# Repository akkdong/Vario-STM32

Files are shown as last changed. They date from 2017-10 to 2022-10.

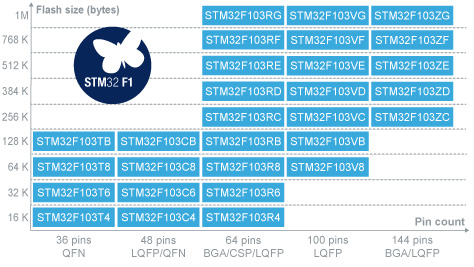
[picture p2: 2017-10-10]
doc/en.STM32F103_line_LN1565.jpg

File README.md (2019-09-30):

# Variometer with STM32

## Variometer Features
* Calculate Vertical Velocity : uses sensor fusion(pressure & accelleration)
* Vario sound
* Receive GPS data
* IGC Logging : save to SD-Card
* BT connectivity : support GPS & Vario NMEA setences
* Firmware update : support Windows application that updates using USB2Serial
* Function Key
	* Change sound level (mute, low, loud)
	* UMS On/Off
	* Calibration On/Off
* Accllerator calibration
* Configuration console
	* View & Update parameters
	* Interactive calibration
	* Support Window or Android applicatioin that uses USB2Serial or BT
* One key Power on/off
* Self Power off
* Low battery detection
* USB suppport : UMS(USB mass stroage), USB2Serial
	* UMS can be enabled by Function key or when power on while functin key is pressed.
	* USB2Serial supports Firmware update & Debugging\
* Status LED : Power, MCU, GPS, BT status notify

## Hardware specifications
* STM32F103CB Processor
* 10DOF IMU : MPU6050, HMC5883, MS5611
* 66ch GPS module : AKS6C
* BT : Bluetooth Specifcation 2.1 support, Calss2, SPP
* Li-po battery & Charger
* Push button On/Off controller
* SD card
* USB : UMS, USB to Serial, DFU
* EEPROM : 32KB I2C
* Piezo speaker

## Device modes
* Vario : default mode
* UMS
* Calibration
* Configuration

## Vario modes
* Init
* Landing
* Flying
* Halt

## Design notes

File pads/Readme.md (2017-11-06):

# Known bugs

* Power on/off does not work.
  * LTC2950 EN pin needs external pull-up.
  * MAX1676 does not cut-off output voltage on shutdown mode
* Charging LED does not turn off even when fullly charged

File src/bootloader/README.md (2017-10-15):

# STM32duino-bootloader

Modify Node. I modify original STM32duino-bootloader for my variometer boards.

Please Note. This code does not work with all STM32F103 Boards

Also Note. Use GCC 4.8 (not 4.9 or newer, as these versions have more aggressive optimisation which causes hardware registers not be read correctly and consequently the bootloader does not work)

Bootloader for STM32F103 boards, for use with the Arduino_STM32 repo and the Arduino IDE

This repo is a derivation of  https://github.com/jonatanolofsson/maple-bootloader (mini-boot branch) which is in turn a derivation of the maple-bootloader created by Leaflabs http://github.com/leaflabs/maple-bootloader

The bootloader has been reworked so that all versions are contained in the Master branch, rather than 1 branch per version / board.

Note.
The upload to RAM option has effectively been removed, as it was useless and caused problems.
The bootloader still has a DFU - AltID for RAM uploads, however this returns an error the host attempts to uplaod to this AltID. The AltID was kept, to allow backwards compatibility with anyone still using the old Maple IDE which has a upload to RAM option.

The makefile now has multple build targets including "maple-mini" (roughly equivalent to the old mini-boot branch), maple-rev3 etc etc.

Additionally the bootloader now works with "generic" STM32F103 boards, which do not have the additional USB reset hardware which all Maple, and Maple mini boards have.

On "generic" boards, the USB reset (to force re-enumeration by the host), is triggered by reconfiguring USB line D+ (PA12) into GPIO mode, and driving PA12 low for a short period, before setting the pin back to its USB operational mode.
This system to reset the USB was written by @Victor_pv.
Note. It is not guaranteed to work on all "generic" STM32 boards, and relies on PA12 having a pull-up resistor of around 1.5k - however most "generic" boards seem to have this.
Its unclear if this method to reset the USB bus conforms precisely to the USB standard, but it seems to work fine on all PC's and Mac's (and Linux boxes) on which its been tested - and seems usable for hobby / non commericial / non-critical systems.

There are multiple build targets for "generic" STM32F103 boards, because each vendor seems to have the "LED" on a different port/pin, and the bootloader flashes the LED to indicate the current operation / state.

So if your board has an LED on pin PC13 the makefile target is "generic-pc13" . At the time of writing the following geneirc targets are available (more may be added without this readme being updated each time, so please check the makefile to see the latest list of build targets)

generic-pc13
generic-pg15
generic-pd2
generic-pd1
generic-pa1
generic-pb9

In addition to the LED, the difference in the build targets is
(a) whether the device has maple USB reset hardware.
(b) Which pin the "button" is attached to.

Note. Most "generic" STM32F103 boards only have a reset button, and not a user / test button. So the bootloader code always configures the Button input pin as PullDown,  hence if a button is not present on the Button pin (Default is PC14), the pin should remain in a LOW state, and the bootloader will assume that the Button is not being pressed.

IMPORTANT.
If you have a board where you have external hardware attached to pin PC12 which will pull this pin HIGH, you will need to make a new build target for you board which uses a different pin for the Button, or completely modify the code so that the Button is ignored.

The configuration for each build target / board is defined in config.h

The Makefile sets the board name as a #define e.g. #define TARGET_GENERIC_F103_PD2, and config.h contains a block of config defines for each board.

e.g.

```
#define HAS_MAPLE_HARDWARE 1
#define LED_BANK GPIOB
#define LED_PIN 1
#define LED_ON_STATE 1
/* On the Mini, BUT is PB8 */
#define BUTTON_BANK GPIOB
#define BUTTON 8
/* USB Disc Pin Setup. USB DISC is PB9 */
#define USB_DISC_BANK GPIOB
#define USB_DISC 9
#define USER_CODE_RAM ((u32)0x20000C00)
#define RAM_END ((u32)0x20005000)
```

Boards which have the Maple USB reset hardware need to defined HAS_MAPLE_HARDWARE

There are definitions for LED_BANK (GPIO Port)
LED pin (Pin in that port)
LED_ON_STATE ( Whether the LED is lit when the pin is high (1) or low (0) - Note. this is because some generic boards have the LED between Vcc and the pin, hence are on when the LED PIN is LOW)

Button bank (port) and pin

For boards with Maple hardware, the "Disconnect" pin USB_DISC need to be defined.
On generic" boards, as this is always PA12 - as USB D+ is always on this pin on STM32F103 devices.
(Note. For generic boards, this define could probably be moved to the usb code as it never changes)

Note.
USER_CODE_RAM and RAM_END are allways the same, and probably need to be consolodated, rather than being defined for each board.

There is no longer a need to configure FLASH SIZE, as this is now detemined by reading the size from a register in the processor.
The Flash page (and hence DFU upload block size) no longer needs to be defined either, as the flash page size is inferred from the total flash size. All devices up to 128kb have a 1k page size, and any board with more then 128k flash have a 2k page size.

Note the code directly links flash page size to DFU block size. It would probably be possible to decouple this and possibly increase upload speeds, but it has not been done as yet.

#####Other improvements on the original Maple bootloader

1. Smaller footprint - now only 8k (This became possible due to code changes by @jonatanolofsson which allowed the GCC optimisation for size flag to be used
2. Additional DFU AltID upload type was added, which allows the sketch to be loaded at 0x8002000 instead of 0x8005000 (due to reduce size of the bootloader is self),
Note. upload to 0x8005000 was retained for backwards compatibility.

If you have questions about the bootloader please raise and issue and I will attempt to answer them.

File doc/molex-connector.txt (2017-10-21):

53047 1.25 pitch Vertical
53048 1.25 pitch Right Angle

51021 1.25 pitch Wire-to-Wire & Wire-to-Board Housing, Female

53398 1.25 pitch Surface Mount, Vertical
53262 1.25 pitch Surface Mount, Right Angle

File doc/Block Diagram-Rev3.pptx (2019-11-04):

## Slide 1

USB

Charger

Regulator

MCU

VCC_USB

VCC_BAT

Reset

VCC_MCU

Battery

VCC_BAT+

Regulator

VCC_PERI1

GPS

BT

Regulator

VCC_PERI2

EEPROM

MMC

EPD

Load Switch

VCC_EXT

IMU

PIEZO

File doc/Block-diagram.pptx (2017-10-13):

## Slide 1

STM32F103C

USB

D+

D-

DISC

I2C1_SCL

I2C1_SDA

IMU

Regulator

VCC

PWM_H

PWM_L

Buzzer

Charger

LiPo

S/W

Regulator

ACC

UART1_RX

UART1_TX

GPS

UART2_RX

UART2_TX

BT

Voltage
Divider

JTAG

SD-Card

SPI2_SCLK

SD_CS

SPI2_MOSI

ADC_POWER

EEPROM

SPI2_MISO

EE_CS

JNTRST

JTDI

JTMS

JTCK

BTN_RESET

JTDO

LED_POWER

NRST

Button

Button

Button

BTN_BOOT

BTN_EXTRA

LED_STATE1

LED_STATE2

LED

LED

LED

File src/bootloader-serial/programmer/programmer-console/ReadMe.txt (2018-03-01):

========================================================================
    콘솔 응용 프로그램 : programmer-console 프로젝트 개요
========================================================================

응용 프로그램 마법사에서 이 programmer-console 응용 프로그램을 만들었습니다.

programmer-console 응용 프로그램을 구성하는 각 파일에 대한
요약 설명이 포함되어 있습니다.

programmer-console.vcxproj
    응용 프로그램 마법사를 사용하여 생성한 VC++ 프로젝트의 기본 프로젝트 파일입니다. 파일을 생성한 Visual C++ 버전에 대한 정보와 응용 프로그램 마법사를 사용하여 선택한 플랫폼, 구성 및 프로젝트 기능에 대한 정보가 포함되어 있습니다.

programmer-console.vcxproj.filters
    응용 프로그램 마법사를 사용하여 생성된 VC++ 프로젝트의 필터 파일입니다. 이 파일에는 프로젝트의 파일과 필터 간의 연결 정보가 들어 있습니다. 이러한 연결은 특정 노드에서 유사한 확장명으로 그룹화된 파일을 표시하기 위해 IDE에서 사용됩니다. 예를 들어 ".cpp" 파일은 "소스 파일" 필터와 연결되어 있습니다.

programmer-console.cpp
    기본 응용 프로그램 소스 파일입니다.

/////////////////////////////////////////////////////////////////////////////
기타 표준 파일:

StdAfx.h, StdAfx.cpp
    이 파일은 미리 컴파일된 헤더(PCH) 파일 programmer-console.pch와 미리 컴파일된 형식(PCT) 파일 StdAfx.obj를 빌드하는 데 사용됩니다.

/////////////////////////////////////////////////////////////////////////////
기타 참고:

응용 프로그램 마법사에서 사용하는 "TODO:" 주석은 사용자가 추가하거나 사용자 지정해야 하는 소스 코드 부분을 나타냅니다.

/////////////////////////////////////////////////////////////////////////////

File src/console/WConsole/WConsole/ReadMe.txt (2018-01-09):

================================================================================
    MFC 라이브러리 : wconsole 프로젝트 개요
===============================================================================

응용 프로그램 마법사에서 이 wconsole 응용 프로그램을 만들었습니다. 이 응용 프로그램은 MFC의 기본 사용법을 보여 줄 뿐만 아니라 응용 프로그램을 작성하기 위한 기본 구조를 제공합니다.

wconsole 응용 프로그램을 구성하는 각 파일에 대한
요약 설명이 포함되어 있습니다.

wconsole.vcxproj
    응용 프로그램 마법사를 사용하여 생성한 VC++ 프로젝트의 기본 프로젝트 파일입니다. 파일을 생성한 Visual C++ 버전에 대한 정보와 응용 프로그램 마법사를 사용하여 선택한 플랫폼, 구성 및 프로젝트 기능에 대한 정보가 포함되어 있습니다.

wconsole.vcxproj.filters
    응용 프로그램 마법사를 사용하여 생성된 VC++ 프로젝트의 필터 파일입니다. 이 파일에는 프로젝트의 파일과 필터 간의 연결 정보가 들어 있습니다. 이러한 연결은 특정 노드에서 유사한 확장명으로 그룹화된 파일을 표시하기 위해 IDE에서 사용됩니다. 예를 들어 ".cpp" 파일은 "소스 파일" 필터와 연결되어 있습니다.

wconsole.h
    해당 응용 프로그램의 기본 헤더 파일입니다.
    여기에는 resource.h를 비롯한 다른 프로젝트별 헤더가 포함되어 있으며 CVarioConsoleApp 응용 프로그램 클래스가 선언되어 있습니다.

wconsole.cpp
    이는 응용 프로그램 클래스 CVarioConsoleApp가 포함된 기본 응용 프로그램 소스 파일입니다.

wconsole.rc
    프로그램에서 사용하는 모든 Microsoft Windows 리소스의 목록입니다. 여기에는 RES 하위 디렉터리에 저장된 아이콘, 비트맵 및 커서가 포함됩니다. 이 파일은 Microsoft Visual C++에서 직접 편집할 수 있습니다. 프로젝트 리소스는 1042에 있습니다.

res\wconsole.ico
    아이콘 파일이며, 응용 프로그램의 아이콘으로 사용됩니다. 이 아이콘은 기본 리소스 파일인 wconsole.rc에 의해 포함됩니다.

res\wconsole.rc2
    이 파일에는 Microsoft Visual C++ 이외의 다른 도구에서 편집한 리소스가 포함되어 있습니다. 리소스 편집기로 편집할 수 없는 모든 리소스는 이 파일에 넣어야 합니다.

/////////////////////////////////////////////////////////////////////////////

응용 프로그램 마법사에서 대화 상자 클래스 하나를 만듭니다.

VarioConsoleDlg.h, VarioConsoleDlg.cpp - 대화 상자
    이 파일에는 CVarioConsoleDlg 클래스가 포함됩니다. 이 클래스는 응용 프로그램의 주 대화 상자에 대한 동작을 정의합니다. 이 대화 상자 템플릿은 wconsole.rc에 있으며, Microsoft Visual C++에서 직접 편집할 수 있습니다.

/////////////////////////////////////////////////////////////////////////////

기타 기능:

ActiveX 컨트롤
    응용 프로그램이 Active X 컨트롤을 지원합니다.

/////////////////////////////////////////////////////////////////////////////

기타 표준 파일:

StdAfx.h, StdAfx.cpp
    이 파일은 미리 컴파일된 헤더(PCH) 파일 wconsole.pch와 미리 컴파일된 형식(PCT) 파일 StdAfx.obj를 빌드하는 데 사용됩니다.

Resource.h
    새 리소스 ID를 정의하는 표준 헤더 파일입니다. Microsoft Visual C++에서 이 파일을 읽고 업데이트합니다.

wconsole.manifest
	응용 프로그램 매니페스트 파일은 Windows XP에서 특정 버전의 Side-by-Side 어셈블리에 대한 응용 프로그램 종속성을 설명하는 데 사용됩니다. 로더는 이 정보를 통해 어셈블리 캐시 또는 응용 프로그램의 private에서 적절한 어셈블리를 로드합니다. 응용 프로그램 매니페스트는 응용 프로그램 실행 파일과 같은 폴더에 설치된 외부 .manifest 파일 형태로서 재배포용으로 포함되거나, 리소스 형태로 된 실행 파일에 포함될 수 있습니다.
/////////////////////////////////////////////////////////////////////////////

기타 참고:

응용 프로그램 마법사에서 사용하는 "TODO:"는 사용자가 추가하거나 사용자 지정해야 하는 소스 코드 부분을 나타냅니다.

공유된 DLL에서 MFC를 사용하는 응용 프로그램의 경우 MFC DLL을 재배포할 필요가 없습니다. 응용 프로그램에서 운영 체제의 로캘과 다른 언어를 사용하는 경우 이에 해당하는 지역화된 리소스인 mfc110XXX.DLL도 재배포해야 합니다.
이러한 두 항목에 대한 자세한 내용은 MSDN 설명서에 있는 Visual C++ 응용 프로그램 재배포 섹션을 참조하십시오.

/////////////////////////////////////////////////////////////////////////////

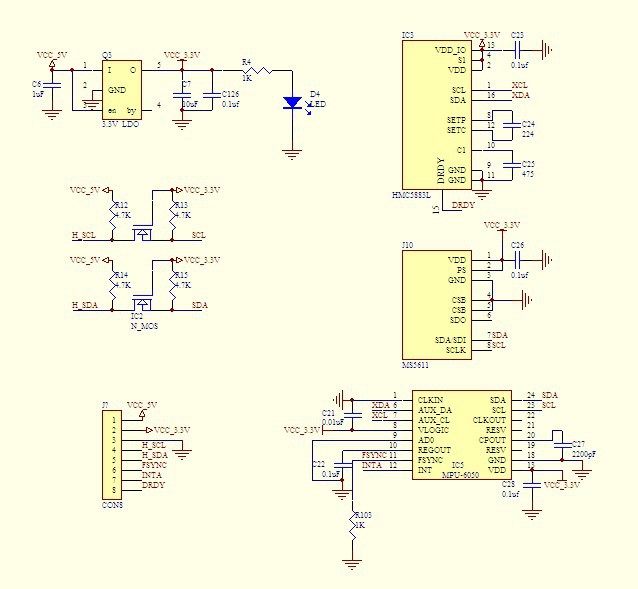
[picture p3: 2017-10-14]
doc/GY-86_Schematic.jpg

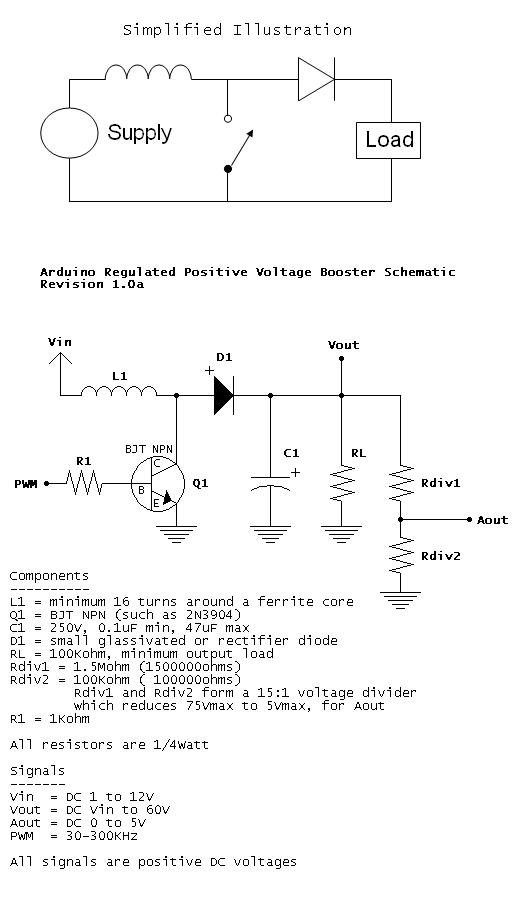
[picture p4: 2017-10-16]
doc/piezo/RegVoltageBoosterSchematic.jpg

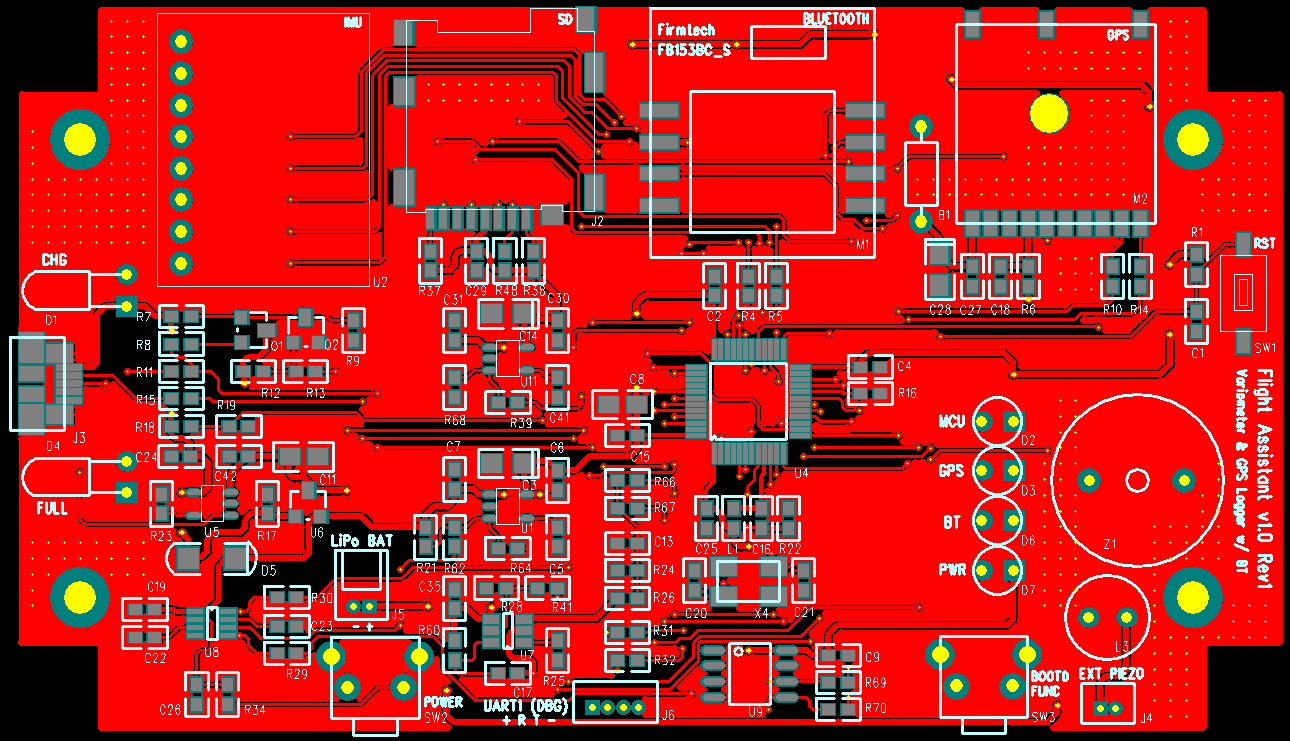
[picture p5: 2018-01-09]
doc/pcb/pcb-top-rev2.png

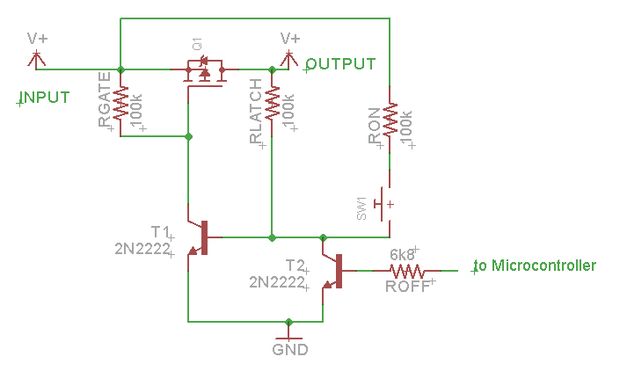
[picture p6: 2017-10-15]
doc/auto power off - 1.jpg

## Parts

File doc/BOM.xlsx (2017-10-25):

Item | Qty | Reference | Part Name | Note
1 | 1 | Q3 | 2SC2383
2 | 3 | U1 U6 U10 | AO3401A
3 | 1 | U9 | AT24C256C | 32KB, I2C
4 | 2 | Q1-2 | BC817-16LT1 | generic NPN transistor
5 | 2 | B1 L1 | BEAD-0603(1608) | 47nH, 300mA
6 | 1 | Z1 | BUZZER | BPE-1404P or BPE-1407P
7 | 1 | C13 | C-N-0603(1608),0.01uF
8 | 16 | C1-2 C4 C6-7 C9 C12 C15-16 C18-19 C22 C24-27 | C-N-0603(1608),0.1uF
9 | 1 | C23 | C-N-0603(1608),0.47uF
10 | 1 | C17 | C-N-0603(1608),1uF
11 | 2 | C20-21 | C-N-0603(1608),20pF
12 | 1 | C5 | C-N-0603(1608),470pF
13 | 1 | C8 | C-N-0805(2012),10uF
14 | 3 | C3 C11 C28 | C-P-0805(2012),10uF
15 | 2 | C10 C14 | C-P-0805(2012),47uF
16 | 1 | L2 | COIL,22uH | SC4532
17 | 1 | L3 | COIL,48mH | RLB0812-22mH/33mH/47mH
18 | 2 | D5 D8 | D-1206(3216),S1M | 1N4004
19 | 1 | M1 | FB153BC_S
20 | 1 | M2 | FGPMMOPA6C
21 | 1 | U2 | GY-86
22 | 6 | D1-4 D6-7 | LED | R/G/Y/B, R/G
23 | 1 | U8 | LTC2950-1
24 | 1 | U7 | MAX1676
25 | 1 | U5 | MCP73831
26 | 4 | X1-3 X5 | MHOLE | 3mm hole, 4mm pad
27 | 1 | U3 | MIC5219-3.3BM5
28 | 1 | J1 | MOLEX-54048-08 | & 51021-08 housing
29 | 1 | J2 | MOLEX-TFLASH-49225-0821
30 | 14 | R4-6 R10 R14 R22 R31-32 R44 R46-47 R49-51 | R-0603(1608),0R
31 | 1 | R8 | R-0603(1608),1.5K
32 | 3 | R3 R21 R45 | R-0603(1608),100K
33 | 17 | R1 R7 R16-17 R27 R35 R37-43 R48 R53-54 R58 R60-61 | R-0603(1608),10K
34 | 1 | R18 | R-0603(1608),15K
35 | 6 | R13 R52 R55-57 R59 | R-0603(1608),1K
36 | 1 | R24 | R-0603(1608),1M
37 | 1 | R28 | R-0603(1608),200R
38 | 1 | R19 | R-0603(1608),22K
39 | 2 | R11 R15 | R-0603(1608),22R | replace 47R
40 | 1 | R30 | R-0603(1608),240K
41 | 1 | R26 | R-0603(1608),270K
42 | 1 | R23 | R-0603(1608),2K
43 | 1 | R29 | R-0603(1608),330K
44 | 1 | R9 | R-0603(1608),33K
45 | 2 | R33 R36 | R-0603(1608),4.7K
46 | 2 | R2 R20 | R-0603(1608),470R
47 | 1 | R12 | R-0603(1608),47K
48 | 1 | R34 | R-0603(1608),5K | replace 4.7K
49 | 1 | R25 | R-0603(1608),NC
50 | 2 | J4-5 | SIP_02 | 54048, 54047 & 51021 housing
51 | 1 | J6 | SIP_04 | & 51021 housing
52 | 1 | U4 | STM32F103C
53 | 3 | SW1-3 | SW-SPST-ITS-1164 | 1/2-KLT-1105VE, 3-SMD Tact
54 | 1 | J3 | USB_TYPEB_MINI | MOLEX-47346-0001
55 | 1 | X4 | XTAL-SMD,8MHz | 3x5 size

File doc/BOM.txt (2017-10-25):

Item	Qty	Reference	Part Name
1	1	Q3	2SC2383
2	3	U1 U6 U10	AO3401A
3	1	U9	AT24C256C
4	2	Q1-2	BC817-16LT1
5	2	B1 L1	BEAD-0603(1608)
6	1	Z1	BUZZER
7	1	C13	"C-N-0603(1608),0.01uF"
8	16	C1-2 C4 C6-7 C9 C12 C15-16 C18-19 C22 C24-27	"C-N-0603(1608),0.1uF"
9	1	C23	"C-N-0603(1608),0.47uF"
10	1	C17	"C-N-0603(1608),1uF"
11	2	C20-21	"C-N-0603(1608),20pF"
12	1	C5	"C-N-0603(1608),470pF"
13	1	C8	"C-N-0805(2012),10uF"
14	3	C3 C11 C28	"C-P-0805(2012),10uF"
15	2	C10 C14	"C-P-0805(2012),47uF"
16	1	L2	"COIL,22uH"
17	1	L3	"COIL,48mH"
18	2	D5 D8	"D-1206(3216),S1M"
19	1	M1	FB153BC_S
20	1	M2	FGPMMOPA6C
21	1	U2	GY-86
22	6	D1-4 D6-7	LED
23	1	U8	LTC2950-1
24	1	U7	MAX1676
25	1	U5	MCP73831
26	4	X1-3 X5	MHOLE
27	1	U3	MIC5219-3.3BM5
28	1	J1	MOLEX-54048-08
29	1	J2	MOLEX-TFLASH-49225-0821
30	14	R4-6 R10 R14 R22 R31-32 R44 R46-47 R49-51	"R-0603(1608),0R"
31	1	R8	"R-0603(1608),1.5K"
32	3	R3 R21 R45	"R-0603(1608),100K"
33	17	R1 R7 R16-17 R27 R35 R37-43 R48 R53-54 R58 R60-61	"R-0603(1608),10K"
34	1	R18	"R-0603(1608),15K"
35	6	R13 R52 R55-57 R59	"R-0603(1608),1K"
36	1	R24	"R-0603(1608),1M"
37	1	R28	"R-0603(1608),200R"
38	1	R19	"R-0603(1608),22K"
39	2	R11 R15	"R-0603(1608),22R"
40	1	R30	"R-0603(1608),240K"
41	1	R26	"R-0603(1608),270K"
42	1	R23	"R-0603(1608),2K"
43	1	R29	"R-0603(1608),330K"
44	1	R9	"R-0603(1608),33K"
45	2	R33 R36	"R-0603(1608),4.7K"
46	2	R2 R20	"R-0603(1608),470R"
47	1	R12	"R-0603(1608),47K"
48	1	R34	"R-0603(1608),5K"
49	1	R25	"R-0603(1608),NC"
50	2	J4-5	SIP_02
51	1	J6	SIP_04
52	1	U4	STM32F103C
53	3	SW1-3	SW-SPST-ITS-1164
54	1	J3	USB_TYPEB_MINI
55	1	X4	"XTAL-SMD,8MHz"

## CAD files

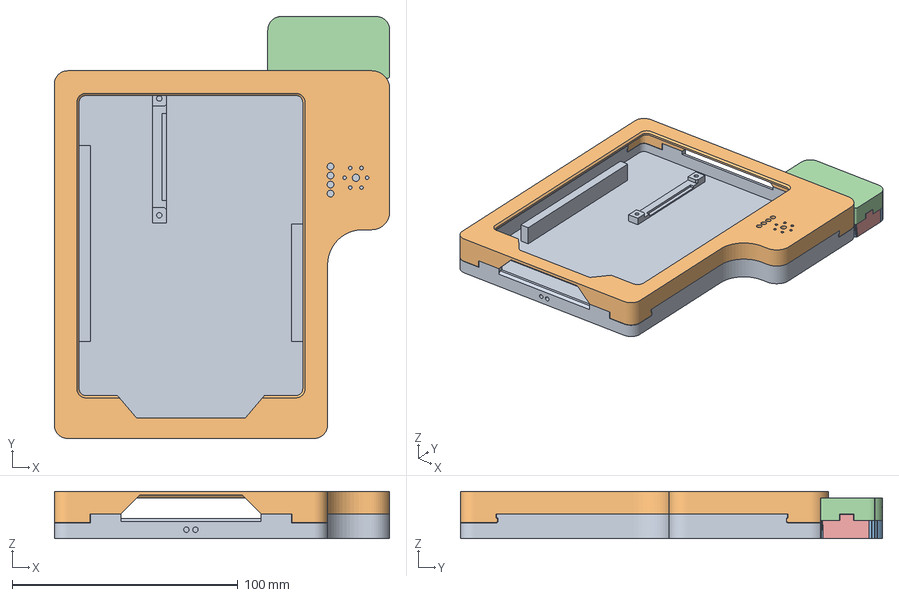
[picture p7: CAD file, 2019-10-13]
case/Kobo.FCStd
148.5 x 186.8 x 21.0 mm
Bottom
Cover
Antenna-Horz-Bottom
Antenna-Horz-Cover
Antenna-Horz-Bottom (Meshed)
Antenna-Horz-Cover (Meshed)

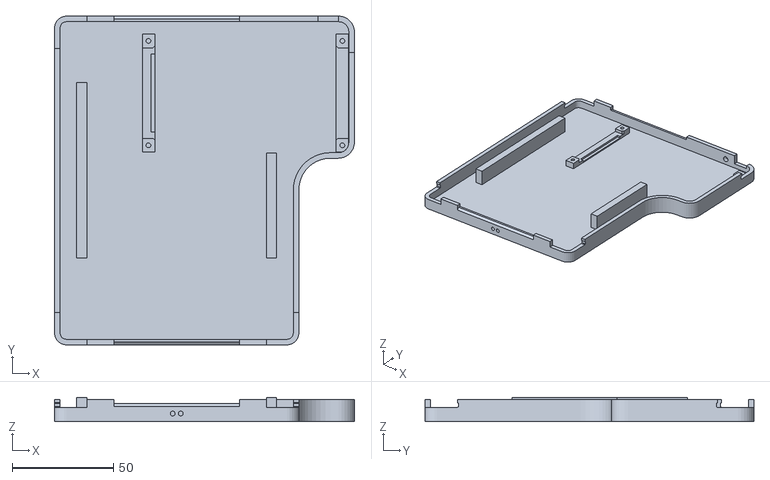
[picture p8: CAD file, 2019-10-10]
case/Kobo-Bottom.stl
148.5 x 162.8 x 12.0

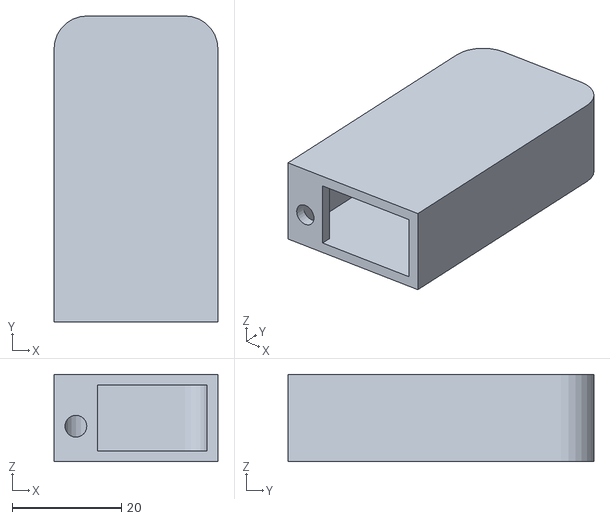
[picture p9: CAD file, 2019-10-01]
case/Kobo-Antenna.stl
30.0 x 56.0 x 16.0

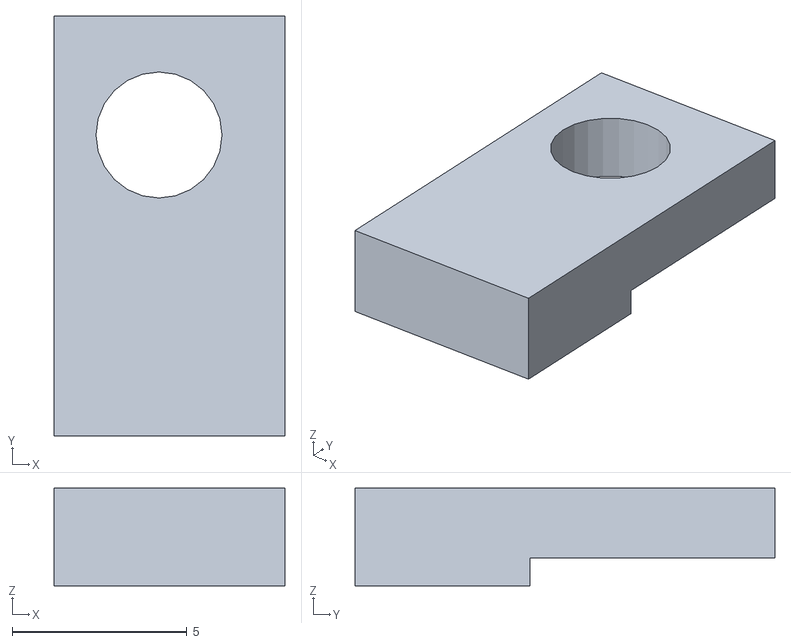
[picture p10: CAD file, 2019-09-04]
case/VarioFix.stl
6.60 x 12.0 x 2.80

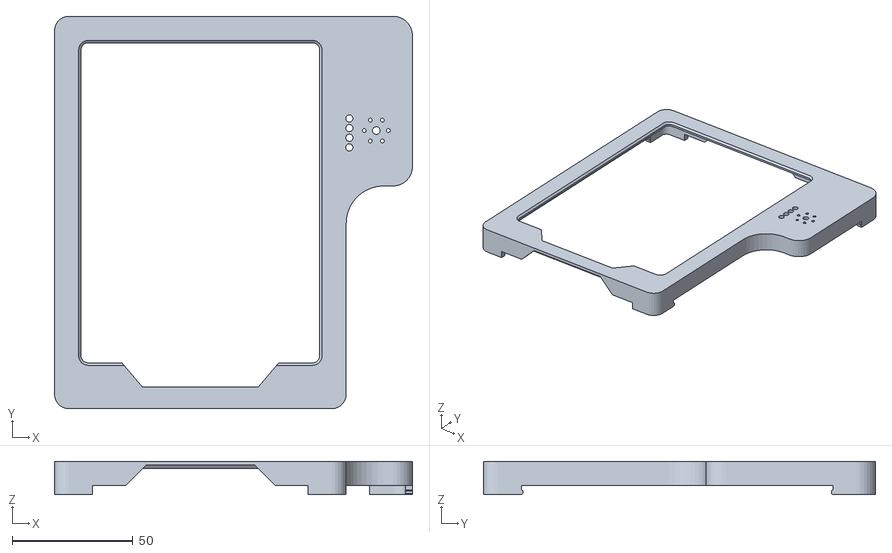
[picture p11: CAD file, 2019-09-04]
case/Kobo-Cover.stl
148.5 x 162.8 x 13.8

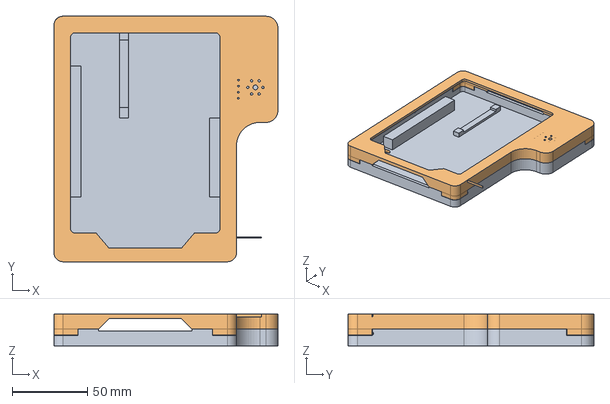
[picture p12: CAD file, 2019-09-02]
case/Kobo-Working.FCStd
148.5 x 162.8 x 21.0 mm
Bottom
Cover

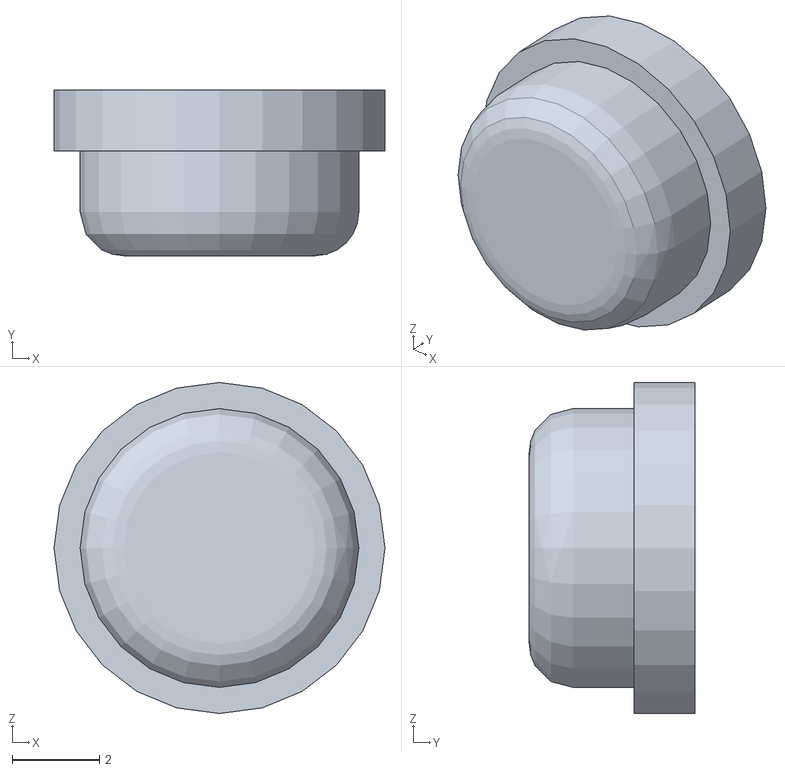
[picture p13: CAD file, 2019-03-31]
case/Case-ButtonSlim.stl
7.60 x 3.80 x 7.60

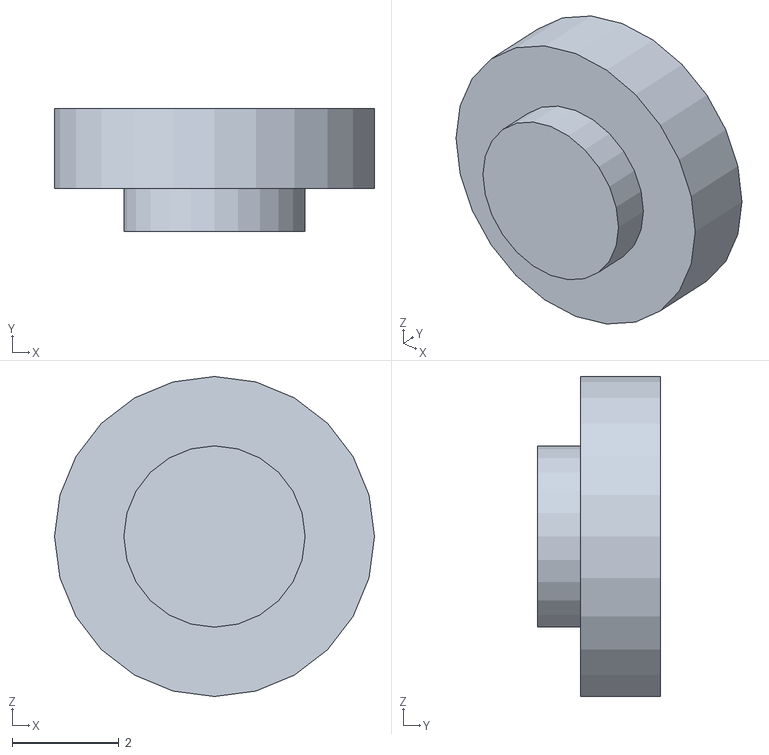
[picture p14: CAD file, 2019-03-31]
case/Case-ButtonSpacer.stl
6.00 x 2.30 x 6.00

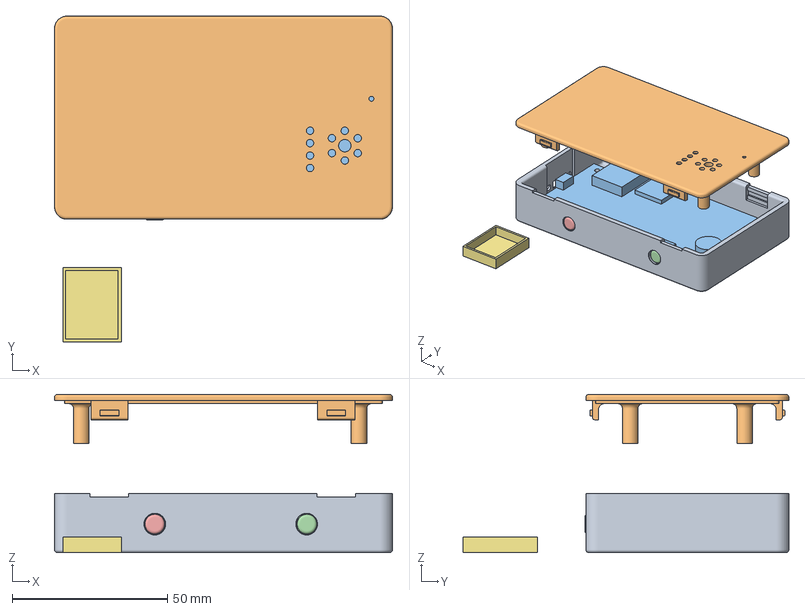
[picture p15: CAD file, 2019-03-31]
case/Variometer-Case-Rev2.FCStd
108.9 x 104.9 x 51.0 mm
BodyBlock
CoverBlock
PCBBlock
SlimButton-NoPocket
SlimButton
ButtonPod
IMUCover
IMUCoverMesh

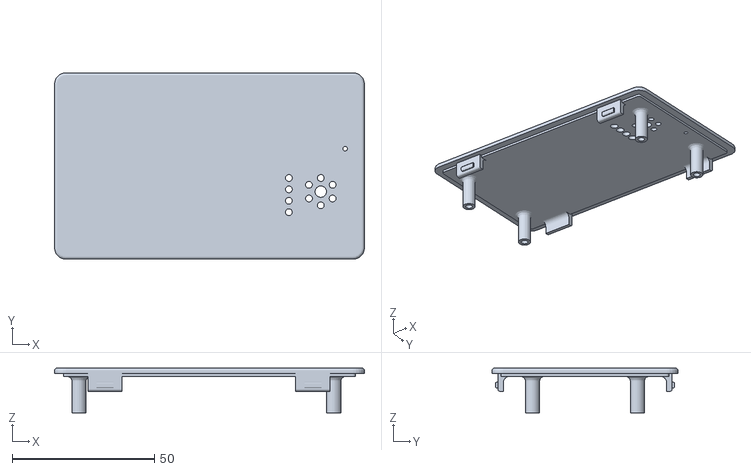
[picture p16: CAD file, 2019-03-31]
case/Case-Cover-3.stl
108.8 x 65.4 x 15.8

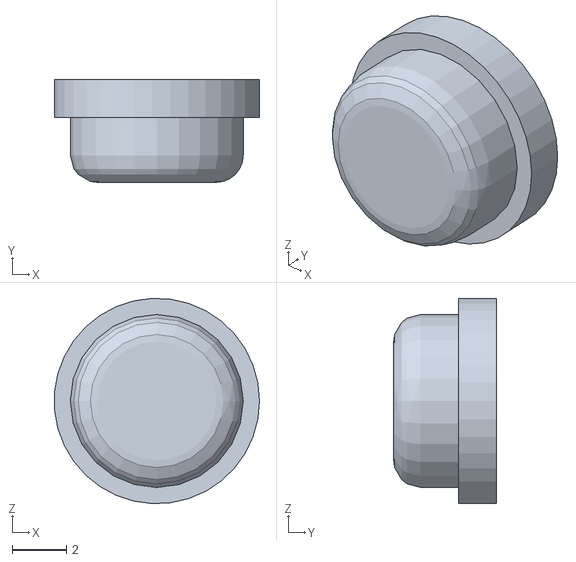
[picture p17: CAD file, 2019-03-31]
case/Case-ButtonSlim-NoPocket.stl
7.58 x 3.80 x 7.59

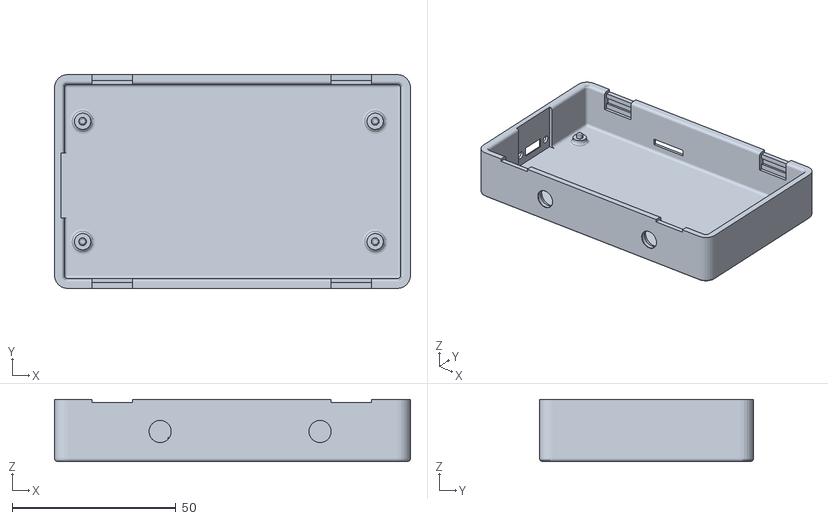
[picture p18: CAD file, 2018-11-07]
case/Case-Body-3.stl
108.8 x 65.4 x 19.0

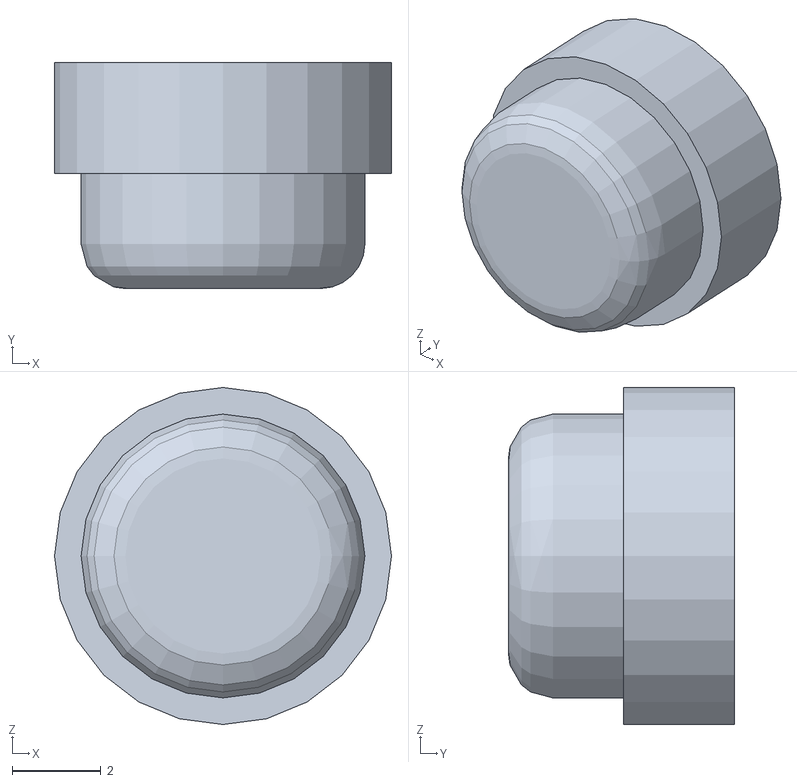
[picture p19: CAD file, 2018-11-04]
case/Case-Button-NoPocket.stl
7.60 x 5.10 x 7.60

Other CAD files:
case/Case-Cover-2.stl
case/Case-Cover.stl
case/Case-Cover-with-Text.stl
case/Case-Body-2.stl
case/Case-Body-Rev2.stl
case/Button.FCStd
case/Case-Body-wt-Hole.stl
case/Case-Body.stl
case/Case-Bottom-2.FCStd
case/Case-Bottom.FCStd
case/Case-Button.stl
case/Case-Cover-Rev2.stl
case/Case-Top-2.FCStd
case/Case-Top.FCStd
case/Sample-Case.FCStd
case/Variometer-Case.FCStd

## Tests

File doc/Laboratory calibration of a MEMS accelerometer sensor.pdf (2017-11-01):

## Laboratory calibration of a MEMS accelerometer sensor

### Irina Georgieva∗1

### , Clemens Hofreither†3

### , Teodora Ilieva‡4

,

### Tihomir Ivanov§1

### , and Svetoslav Nakov¶2

1

### Institute of Mathematics and Informatics, Bulgarian Academy of Sciences

2

### Institute of Mechanics and Biomechanics, Bulgarian Academy of Sciences

3
Institute of Information and Communication Technologies,

### Bulgarian Academy of Sciences 4Soa University, St. Kliment Ohridski

## 1 Introduction

Nowadays, systems, using microelectromechanical systems (MEMS) sensors (e.g. accelerometers, gyroscopes, etc.) nd more and more applications. For instance, they are used for video stabilization, mobile applications and many other things. Among the reasons for their wide use is the fact that they are very cheap and have miniature size (usually less than 10x10x5 mm) and consume little power. However, there are a lot of unexplored elds (like navigation) where they could be used once the necessary mathematical knowledge is developed. For further information, see for example [4].
| In the present work we address MEMS accelerometers in particular. There
are many sources of error that aect their behaviour [4]. In this report, we
| ∗irina@math.bas.bg †chofreither@numa.uni-linz.ac.at ‡dorkata@gmail.com §tihomir_ivanov@ymail.com ¶sisqo_nakov@yahoo.com

1

present two mathematical models and associated algorithms for calibrating the device, i.e. compensating for the constant bias error (the oset of its output signal, when the device does not undergo any acceleration), scaling errors (the deviation of the accelerometer's scale from the unit we want to use, like m/s²
) and nonorthogonality of the axis.

## 2 Approach 1

This approach was studied by Teodora Ilieva, Tihomir Ivanov, and Svetoslav Nakov.
We have a system, consisting of three accelerometers, that measure the linear acceleration in three almost orthogonal directions. We shall assume that the angle between each two of those directions is 90◦ ± 2% [5]. The relationship between accelerometer's outputs and the measured acceleration can be well modeled as a linear function [1]. In Subsection 2 we present the calibration algorithm. Similar approach to the problem is proposed, e.g., in [2], [3] (see also the references within those papers). There a six-parameter and a nine-parameter linear models are developed for calibrating the device. Both of those approaches use an orthogonal coordinate system, with respect to which the corresponding analysis is carried. We study the problem by working in the coordinate system dened by the directions in which the accelerometers measure linear acceleration. We nd this to be the more natural way and, thus, simplifying the analysis. Also, an usual thing to do is to approximate the sine and the cosine functions of small angles with the respective angles (which leads to the linearity of the aforementioned models). We do not use this approximation in order to obtain maximal accuracy in the model.
In Subsection 3 we study computationally the error that can be caused by not considering the non-orthogonality of the axis. We show that even small deviations in the directions of the accelerometers can lead to catastrophic error in the estimated position of the body within a few seconds of integrating.

2.1 Mathematical Model Describing the Relationship Between the Measured and the Real Values of the Acceleration

Let aˆx, aˆy and aˆz be the real values that the accelerometers show and ax, ay and az be the corresponding calibrated values of the acceleration in the x, y and z directions, respectively, with ~e1, ~e2 and ~e3 being unit vectors in those

| 2

directions. We use the following model to calibrate the accelerometers [1]:

ax = ( ˆax − s1)/b1
ay = ( ˆay − s2)/b2
az = ( ˆaz − s3)/b3
, | (1)

where s1, s2, s3 (which we call shifts) and b1, b2, b3 (which we call scaling coecients) are yet to be determined. In matrix form (1) can be written as

ax
ay
az

| {z }
a

=

1/b1 | 0 | 0
0 | 1/b2 | 0
0 | 0 | 1/b3
| | {z | }
T

abx
aby
abz

| {z }
ab

−

s1/b1
s2/b2
s3/b3
| | {z | }
s

Using the introduced notation, we obtain the equation

a = Tab − s | (2)

Proposition 1. If we assume that the axis of the accelerometers are orthogonal, then the acceleration is

aorth := q
a

2
x + a

2
y + a

2
z

Proof. The proof is obvious, using the fact that the sum of the squares of the directional cosines is 1.

Since the axis are not orthogonal, let us denote the angles between the axis as follows (see Fig.1):

φ := 6 (Ox, Oy), ψ := 6 (Ox, Oz), θ := 6 (Oy, Oz) | (3)

Let ~a be an arbitrary acceleration acting on the sensor. Let ax, ay and az be the ane projections of ~a onto the x, y and z axis, respectively. It is important to note that the measured values¹ of the acceleration in the x, y and z directions are not the ane projections of ~a onto the axis. Let us denote (see Fig.1)

α := 6 (~a, ~e1), β := 6 (~a, ~e2), γ := 6 (~a, ~e3)

It can be easily seen that the following Lemma holds true:

1For the time being, let us think that the accelerometeres measure correctly, i.e. ax, ay and az are the measured values from the accelerometers.

3

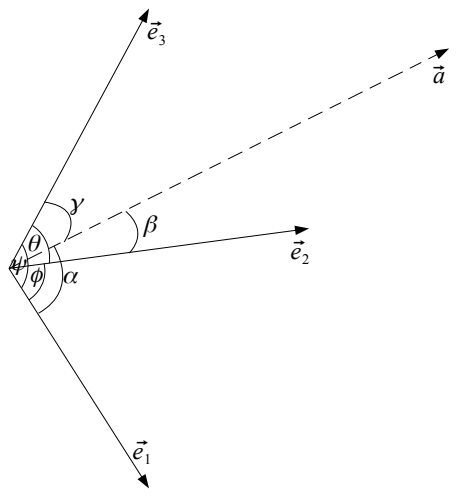
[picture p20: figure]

Figure 1: Acceleration vector in the ane coordinate system

Lemma 1. The equations

ax = k~akcos α
ay = k~akcos β
az = k~akcos γ

(4)

are valid.

We want to express the ane projections ax, ay and az of ~a onto the coordinate axis with ax, ay and az.

Lemma 2. For the ane projections of the acceleration ax, ay and az the following equalities hold true:

ax =

− sin²
θax + (cos φ − cos θ cos ψ)ay + (cos ψ − cos φ cos θ)az −1 + cos² φ + cos² ψ + cos² θ − 2 cos φ cos ψ cos θ

ay =

(cos φ − cos θ cos ψ)ax − sin² ψay + (cos θ − cos φ cos ψ)az −1 + cos² φ + cos² ψ + cos² θ − 2 cos φ cos ψ cos θ

az =

(cos ψ − cos φ cos θ)ax + (cos θ − cos φ cos ψ)ay − sin² φaz −1 + cos² φ + cos² ψ + cos² θ − 2 cos φ cos ψ cos θ

(5)

4

Proof. We have
~a = ax ~e1 + ay ~e2 + az ~e3, | (6)

where ~e1, ~e2 and ~e3 are the unit vectors in the x, y and z directions, respectively. Consecutively, we take the scalar products of the both sides of (6) with ~e1, ~e2, ~e3 and obtain:

(~a, ~e1) = ax + ay cos φ + az cos ψ (~a, ~e2) = ax cos φ + ay + az cos θ (~a, ~e3) = ax cos ψ + ay cos θ + az

(7)

Taking into account (4) we obtain
1 | cos φ cos ψ
cos φ | 1 | cos θ
cos ψ cos θ | 1

ax
ay
az
- =

ax
ay
az
- (8)

We solve the system (8) and obtain (5).

Remark 1. Let us note that the system (8) has diagonally dominant matrix and, therefore, it has a unique solution.
Remark 2. In matrix form, equations (5) can be rewritten as

a = Ta,

where:

a =

ax
ay
az
- , T =

1
den

− sin²
θ | cos φ − cos θ cos ψ cos ψ − cos φ cos θ
cos φ − cos θ cos ψ | − sin² ψ | cos θ − cos φ cos ψ
cos ψ − cos φ cos θ cos θ − cos φ cos ψ | − sin² φ
- ,

den = −1 + cos² φ + cos² ψ + cos² θ − 2 cos φ cos ψ cos θ, a =

ax
ay
az

Lemma 3. For the acceleration anonorth the following holds true

anonorth =

q
ax

2 + ay

2 + az

2 + 2axay cos φ + 2axaz cos ψ + 2ayaz cos θ. (9)

Proof. Taking a = anonorth = (ax, ay, az) in (6) and taking the scalar squares of both sides, we obtain

(anonorth, anonorth) = ax

2+ay

2+az

2+2axay(~e1, ~e2)+2axaz(~e1, ~e3)+2ayaz(~e2, ~e3),

where ~e1, ~e2, ~e3 are the unit vectors along the axis. Taking into account (3),
(9) follows directly.

5

We substitute (5) into (9) and simplify to obtain the following:

Proposition 2. The equality

anonorth =

r
numerator
denominator , | (10)

where

numerator =2(−1 + 1 cos 2θ)a

2
x + 2(−1 + 1 cos 2ψ)a

2
| y + 2(−1 + 1 cos 2φ)a
| 2
| z
+ 8(cos φ − cos ψ cos θ)axay + 8(cos θ − cos φ cos ψ)ayaz + 8(cos ψ − cos φ cos θ)axaz;
denominator =2 + 2 cos 2φ + 2 cos 2ψ + 2 cos 2θ − 8 cos φ cos ψ cos θ

holds true.

Now we shall derive an explicit expression for the calibrated values of the acceleration in an orthonormal cooridnate system, given the data, measured by the sensors.

Proposition 3. Let ~e1, ~e2, ~e3 be the unit vectors in the directions, dened by the accelerometers' axis. Let us introduce an orthonormal coordinate system Of~
1,f~

2,f~
3

, where ~f1 ≡ ~e1,

~f2 is in the ~e1 ~e2 plane. Then the following equality is valid:

~e1
~e2
~e3
- = T

orth

~f1
~f2
~f3

- , | (11)

where

T

orth
=

1 cos φ | cos ψ

0 sin φ

cos θ − cos φ cos ψ
sin φ

0 0

p
1 − cos² φ − cos² ψ − cos² θ + 2 cos φ cos ψ cos θ sin φ

(12)

Proof. Let us denote (see Fig. 2)

ξ := 6 (~e3,

~f2), η := 6 (~e3,

~f3).

6

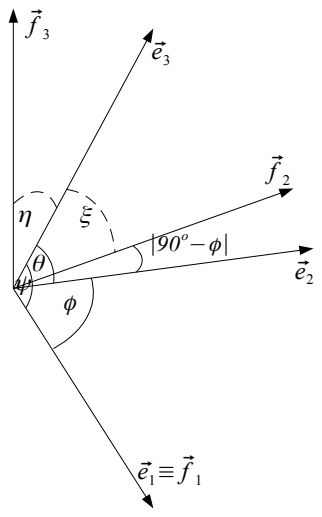
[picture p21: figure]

Figure 2: Orthonormal coordinate system

Since ~f2 lies in the ~e1 ~e2 plane and ~f1 ≡ ~e1 we have the relationship

~e2 = b1

~f1 + b2

~f2, | (13)

where b1 and b2 are real numbers. By taking the inner product of (13) successively with ~f1 and ~f2 we obtain

b1 = cos φ, b2 = cos|90◦ − φ|= sin φ

Therefore, we have
~e2 = cos φ~f1 + sin φ~f2

and, thus,
~f2 = −

cos φ
sin φ

~e1 +

1
sin φ
~e2. | (14)

Analogously, we obtain
~e3 = cos ψ~f1 + cos ξ

~f2 + cos η

~f3,

By taking into account (14), we obtain

cos ξ =

D
~e3,

~f2

E
=
~e3, −

cos φ
sin φ

~e1 +

1
sin φ

~e2

= −

cos φ
sin φ

cos ψ +

cos θ
sin φ

=

cos θ − cos φ cos ψ
sin φ

7

Furthermore, since ~e3 is a vector in the orthonormal coordinate system Of~
1f~

2f~
3
and the angles with the axis being ψ, ξ and η, respectively the following holds true:
cos²

η + cos²

ξ + cos² ψ = 1

cos η =

p
1 − cos² ξ + cos² ψ

=

p
1 − cos² φ − cos² ψ − cos² θ + 2 cos φ cos ψ cos θ sin φ
Let us note, that we have used the fact that η is small angle and, therefore, cos η > 0.

Corollary 1. Let us have an arbitrary acceleration ~a with coordinates in the ane coordinate system O~e1 ~e2 ~e3

, dened by the accelerometers' axis, ax, ay, az, respectively. Let the corresponding coordinates in the Of~
1f~

2f~
3

coordinate
system (dened as in Proposition 3) be ax

orth
, ay

orth and az

orth. Then we
have

ax

orth
ay

orth
az

orth

- = T

orth

ax
ay
az
- , | (15)

where T

orth is dened as (12).

Let us denote

a

orth :=

ax

orth
ay

orth
az

orth

- , a :=

ax
ay
az

Furthermore, let is take into account (2), Remark 2 and Corollary 1 and the notation, introduced in those. Then we obtain the following important result:

Theorem 1. Let abx, aby and abz be the values shown by the accelerometers at a certain time and ax

orth
, ay

orth and az

orth be the coordinates of the corresponding acceleration in the orthonormal coordinate system, dened in Proposition
3. Then the following holds true:

a

orth = T

orthT Tab − T

orthTs. | (16)
2.2 | The Calibration Algorithm

Let us rst note that when the device does not undergo any acceleration, then the length of the vector that the acceleraometers should show is equal

8

to the acceleration due to the gravitational force. The reason for this fact is that the accelerometers do not measure acceleration directly, but force. Now we are ready to explain the algorithm itself.

1. First, we make measurements with the three accelerometer sensors in 20 dierent positions, when the device does not undergo any acceleration. Let us denote those measurements with aˆ

(i)
, where i = 1, 20.
2. We make a rough estimate of the parameters in order to evaluate their signs. We achieve this by considering the simplied model, assuming the axis are orthogonal. Therefore, we nd the values that minimize the sum
X

20

i=1

(Taˆ
(i) − s)
T
(Taˆ
(i) − s) − g
2

2

3. Using a least squares t, we nd the parameters in the model that minimize the sum
X

20

i=1

h
(T

orthT Taˆ
(i) − T

orthT s)
T
(T

orthT Taˆ
(i) − T

orthT s) − g
2

i2
, (17)

under the restrictions, imposed for the signs of the parameters by Step 2.

Let us note that Step 2 is important, because otherwise the numerical methods that we use for minimizing (17) do not always converge to the right values for the estimated parameters.

### 2.3 Estimates for the Error Due to Nonorthogonality

We want to evaluate what is the error that can be caused by not considering the nonorthogonality of the axis. Let us denote

| err(ax, ay, az, φ, ψ, θ) := |anonorth − aorth|.

Since in the calibration procedure we use the fact that when the accelerometers are at rest, then the only acceleration that they measure is due to gravity, we consider the following extremal problem:

Problem 1.
| err(ax, ay, az, φ, ψ, θ) −→ max, anonorth = g, 0.98π ≤ φ, ψ, θ ≤ 1.02π, (18)

where g is the gravitational acceleration.

| 9

Let us note that the restrictions for φ, ψ, θ are imposed because of the up to 2% nonorthogonality of the axis.
By solving this problem numerically, we obtain the estimate of the maximal error
max err(ax, ay, az, φ, ψ, θ) ≈ 0.3130299 m/s²

This value is reached, for example at

ax = ay = az ≈ 5.48114, φ = ψ = θ ≈ 1.60221

Next, we want to give an estimate for the upper bound of the relative error that can be reached when the accelerometer measures an arbitrary acceleration. We assume consecutively that in each direction the accelerometer can measure acceleration up to ±4g, ±8g, ±16g. In all the cases the estimate is approximately the same.

Problem 2.

anonorth − aorth

anonorth

−→ max,

− 16g ≤ ax, ay, az ≤ 16g,
0.98π ≤ φ, ψ, θ ≤ 1.02π,

(19)

The numerical solution of this extremal problem is approximately 3.192%. Next, we present a histogram which represents the distribution of the relative error for values of φ, ψ, θ, respectively 1.53938, 1.60221, 1.60221, which are the estimated with the calibration procedure values for the sensor used in the tests (see Fig.3).

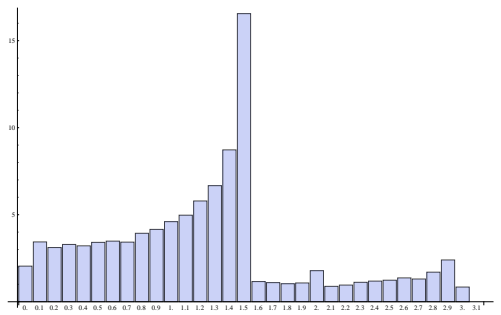
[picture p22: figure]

0. 0.1 0.2 0.3 0.4 0.5 0.6 0.7 0.8 0.9 1. 1.1 1.2 1.3 1.4 1.5 1.6 1.7 1.8 1.9 2. 2.1 2.2 2.3 2.4 2.5 2.6 2.7 2.8 2.9 3. 3.1
Figure 3: Distribution of the relative error

In order to be able to understand the jump in the histogram (Fig.3), we present geometrically the domains in R

3 where the relative error is respectively ≤ 1.4%, ≥ 1.4%½ ≤ 1.6%, ≥ 1.6% (see Fig.4). We assume again that

10

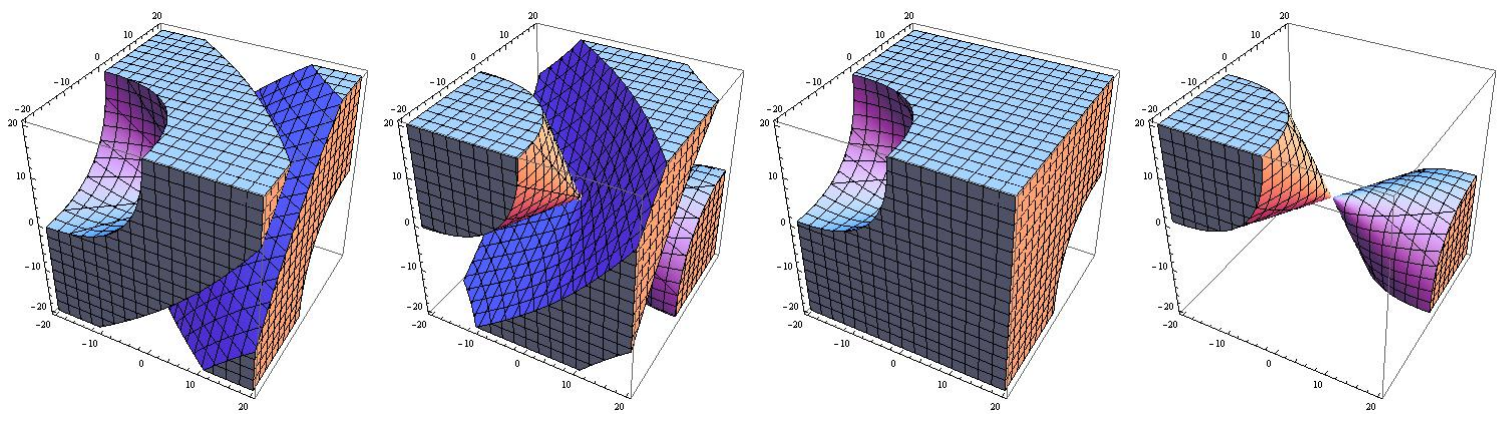
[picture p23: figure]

(a) relative error ≤
1.4%
(b) relative error ≥
1.4%
(c) relative error ≤
1.6%
(d) relative error ≥
1.6%

Figure 4: Domains in R

3
for the relative error

φ, ψ, θ are, respectively 1.53938, 1.60221, 1.60221, and ax, ay, az lie in the interval [−20, 20].
All of those results show that the error that is due to the non-orthogonality of the axis is very serious one and cannot be neglected in order to obtain a linear model for the acceleration.

### 2.4 Conducted Experiments

In this subsection we present some experiments, that we have conducted in order to test the algorithm that we propose. We have tested it with 3 datasets from 3 dierent phones, each consisting of averaged measurements of the sensors in 27 dierent positions when the device does not undergo any acceleration. We have used 20 of those positions for calibrating the device and the other 7 we have used to check the results, by comparing the already calibrated acceleration with g.

- Dataset 1. In Table 1 the measured data from the three accelerometer
| sensors is shown.
| First, we calibrate the device, using positions 120, i.e. we nd the values of the parameters, that minimize the sum

X

| 20

i=1

h
(T

orthT Taˆ
(i) − T

orthT s)
T
(T

orthT Taˆ
(i) − T

orthT s) − g
2

i2
,

where aˆ

(i)
is the vector, consisting of the measurements in the i-th position in Table 1. We obtain the following values for the

11

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

Analogously, using positions 323, we obtain:

s1 → 0.318321, s2 → 0.322794, s3 → −1.09059, b1 → −1.00472, b2 → −1.00124, b3 → −0.989255, φ → 1.56932, ψ → 1.5709, θ → 1.57296

Using the obtained values for the calibration parameters, we evaluate the relative error over all measured positions, i.e. we estimate

a − g
g

,

where a is the absolute value of the acceleration, calculated with formula (16). In all cases it is less than 0.21%.

- Dataset 2. In Table 2 the measured data from the three accelerometer sensors from the second device is shown.

Using positions 120, we obtain:

s1 → −0.469784, s2 → 0.608425, s3 → 0.208206, b1 → −0.999573, b2 → −0.989443, b3 → −1.01176, φ → 1.56219, ψ → 1.56969, θ → 1.57057

Using positions 323, the estimated values are:

s1 → −0.466405, s2 → 0.616422, s3 → 0.207149, b1 → −0.999212, b2 → −0.989644, b3 → −1.01181, φ → 1.55782, ψ → 1.56827, θ → 1.57215

Once again, the values are very close to one another. The worst relative error that is reached with those calibrations is below 0.45%.

- Dataset 3. In the last dataset, shown in Table 3, it is important to note, that the measurements from positions 3 and 21 are very similar to each other. As one can see from the results shown below, if we use both those position for calibration purposes the result is much worse.

Using positions 120 (i.e. using only one of the similar rows of data), we obtain a relative error of 0.26%
Using positions 323, we obtain a relative error of 0.98%

This shows that it is important to make the measurements in distinct positions. Otherwise, the least-squares t is biased towards one position and the result gets worse.

13

Position | x | y | z
1 | 7,324190906 | 1,250997715 | -5,785632422
2 | -8,334818875 | 1,423071223 | 6,075933722
3 | -0,55309323 | -1,556750779 | -9,465058152
4 | 0,3963949 | -2,401782608 | 9,590842176
5 | 4,468067668 | 0,438564599 | 8,815483348
6 | -0,25604359 | -8,251388776 | 4,231704803
7 | -10,19639516 | -0,540933147 | -0,043947822
8 | 9,243301882 | -0,489659084 | 0,177376713
9 | 5,184601909 | 0,464227916 | -7,888789547
10 | -7,133046458 | 0,486715023 | 7,492167273
11 | -3,544315793 | -5,885572603 | -6,514445229
12 | 1,927551054 | -5,721122639 | 7,317886686
13 | 0,712132815 | 0,611587605 | 10,05427574
14 | -0,516080232 | -1,053660856 | -9,563502952
15 | -0,482513916 | -0,519767116 | 10,04926657
16 | -0,366261687 | 1,69466758 | -9,659420825
17 | -1,770079301 | 0,62190275 | 10,02684107
18 | 0,714671068 | 0,553163819 | -9,626586644
19 | -0,557896244 | 1,798565701 | 10,05206135
20 | -0,633628967 | 7,907637143 | 6,736185309
21 | -0,244376238 | 7,911662259 | -6,344980284
22 | -0,391871362 | -6,71082086 | -6,278043744
23 | -1,109805182 | -6,966091847 | 6,382627512
24 | -10,2685151 | 0,6944625 | 0,553426001
25 | 9,263098671 | 0,708257972 | 1,16414443
26 | -0,341591276 | -9,051813894 | 0,526102398
27 | -0,766906823 | 10,32812321 | 0,883673299
28 | 0,139849901 | 0,372395084 | -9,689413968
29 | -0,825407808 | 0,440694427 | 10,10000846

Table 2: Dataset 2

### 2.5 Conclusion

We have derived an explicit formula for the linear acceleration, given the values of the accelerometers and the angles between the axis of the sensors. We have explained how one can nd an approximation of those angles and the shifts and scaling coecients, given some measurements of the sensors, when the system does not undergo any acceleration. We have run some numerical experiments in order to understand better the error, caused by

| | 14

Position | x | y | z
1 | 0,686143985 | 9,693013241 | 0,146230973
2 | 0,307313184 | -9,555131822 | 0,121707371
3 | 10,20588166 | 0,146627372 | 0,293913142
4 | -9,235730337 | 0,149835656 | -0,153514714
5 | 0,277144172 | -0,108499369 | 9,72381854
6 | 0,652333397 | 0,026782191 | -9,867581581
7 | 2,819218128 | 0,00984892 | 9,453752615
8 | -1,006468208 | 0,586054944 | 9,610065897
9 | 10,10396889 | 0,089937928 | -1,625049867
10 | -1,605962585 | 0,058272144 | -9,639987664
11 | 0,246794337 | 1,126126555 | 9,709396155
12 | 0,706211903 | -3,139230967 | -9,302827738
13 | 7,728566894 | 0,248629672 | 6,471431237
14 | 2,053861069 | -2,927665847 | 9,11283197
15 | 5,742237957 | 0,041531765 | 8,152279472
16 | 1,604557037 | 0,951821853 | -9,754449668
17 | 1,029262184 | 1,996550095 | 9,543562547
18 | 0,041407842 | -2,516368282 | 9,358991009
19 | 2,730162016 | -8,137597633 | -4,711984149
20 | -2,924918942 | -6,411393964 | 6,335544161
21 | 10,18267071 | 0,144573621 | 0,312617999
22 | 3,908533423 | -8,83618239 | -1,558956159
23 | -4,59854197 | -8,151722848 | 0,065404421
24 | -1,674747469 | 9,466063897 | 0,036135226
25 | 10,04636598 | 1,799748205 | 0,246702889
26 | 7,685992297 | 6,529638446 | 0,083514447

Table 3: Dataset 3

the nonorthogonality of the axis.
Future work on the topic could include studying the error with which the calibration parameters are evaluated with the procedure that we propose. Also, the optimal positions in which the calibration data is to be collected, should be determined. Probably, more investigation on the errors can give some insights about those positions.

## 3 Approach 2

This approach was studied by Irina Georgieva and Clemens Hofreither.

| | 15

### 3.1 Mathematical problem description

We are concerned with an end-user device (e.g., smart phone) with a built-in accelerometer which measures accelerations along three axes. In the following, we refer to the true acceleration which acts on the device by a, and to the measurements which its sensor outputs by m.
In practice, the measurements m will not coincide with the true physical acceleration a due to many factors, among these,
- scaling errors,
- crosstalk,
- oset errors,
- non-orthogonality of the accelerometer axes,
- time-dependent noise,
- etc.

We want to nd and calibrate a model which allows us to reconstruct as well as possible the true accelerations from the measured data,

| m 7→ a,

by taking into account the systematic errors in the accelerometer of one particular device.
For all further considerations, we x a coordinate system relative to the phone as shown in the below picture.

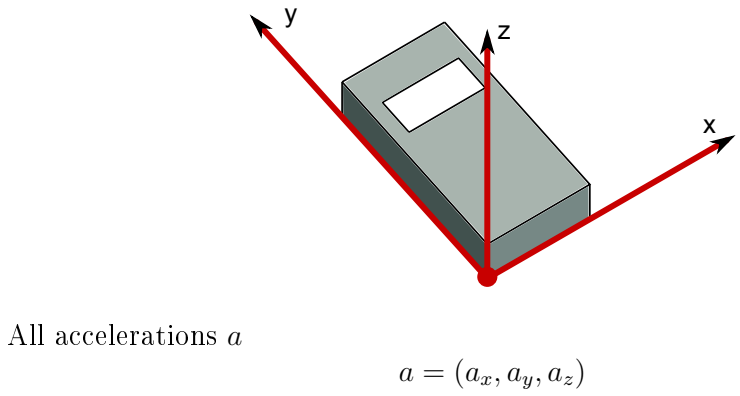
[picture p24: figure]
All accelerations a

acting on the phone will be considered in this coordinate system. We point out that this coordinate system may not be aligned with the axes of the accelerometer, and there is no need for this.

16

### 3.2 Mathematical model

We assume an ane-linear relationship between the measurements m = (m1, m2, m3) and the true acceleration vector a = (a1, a2, a3), that is, the function m = F(a) should be of the form

m = F(a) = Xa + y.

Here, X ∈ R

3×3
is an unknown matrix, and y ∈ R

3
is an unknown vector.
In this model, the diagonal of X may represent the scaling error, the o-diagonal entries of X the crosstalk factors, and y the oset. However, X can also represent arbitrary rotations in the case that the accelerometer sensor is not installed in an axis-aligned way in the device.
Once we have computed X and y, we can simply invert the above formula to obtain the true acceleration a from measurements m by the formula

a = F

−1
(m) = X

−1
(m − y). | (20)

This model has 12 parameters, namely, the 9 entries of X plus the 3 entries of y.
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

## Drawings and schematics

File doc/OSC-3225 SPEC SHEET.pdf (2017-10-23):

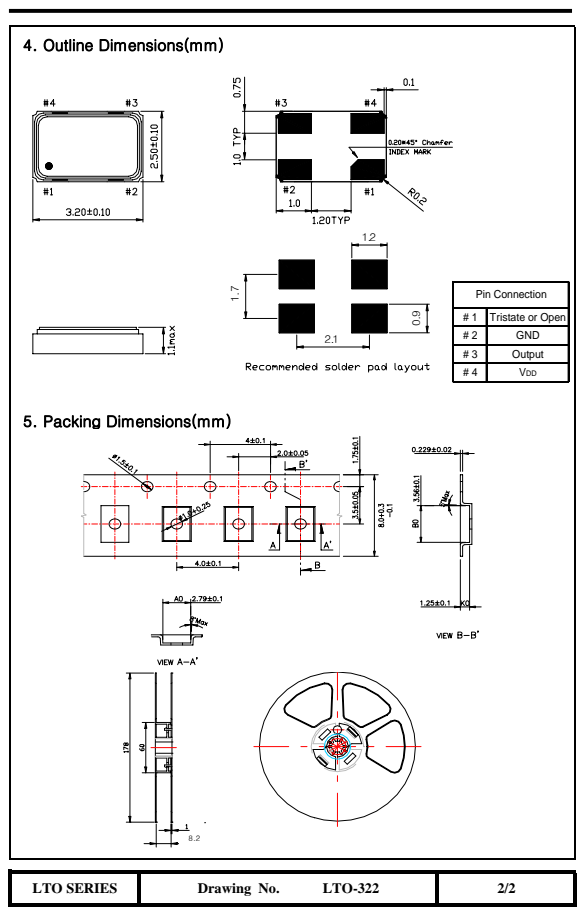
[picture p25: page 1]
27.0000MHz(3.0V); CSC3K270000BEVRS00; LTO SERIES; Drawing No.; LTO-322; Pin Connection

4. Outline Dimensions(mm)

# 1 | Tristate or Open
# 2 | GND
# 3 | Output
# 4 | VDD

5. Packing Dimensions(mm)

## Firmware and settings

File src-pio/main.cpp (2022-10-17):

// main.cpp
//

#include <Arduino.h>
#include <Wire.h>

#include <DefaultSettings.h>
#include <SerialBluetooth.h>
#include <I2CDevice.h>
#include <EEPROMDriver.h>
#include <GlobalConfig.h>
#include <NmeaParserEx.h>
#include <InputKey.h>
#include <OutputKey.h>
#include <FunctionKey.h>
#include <FuncKeyParser.h>
#include <LEDFlasher.h>
#include <ToneGenerator.h>
#include <ToneFrequency.h>
#include <TonePlayer.h>
#if VARIOMETER_CLASSS == CLASS_KALMANVARIO
#include <KalmanVario.h>
#else
#include <Variometer.h>
#endif // VARIOMETER_CLASSS == CLASS_KALMANVARIO
#include <VarioBeeper.h>
#include <VarioSentence.h>
#include <BluetoothMan.h>
#include <IGCLogger.h>
#include <BatteryVoltage.h>
#include <CommandParser.h>
#include <ResponseStack.h>
#include <SensorReporter.h>
#include <AccelCalibrator.h>

#include "ParamVarMap.h"
#include "Sd2CardEx.h"
#include "UsbMassStorage.h"
#include "UMS_mal.h"

#include <libmaple/bkp.h>
#include <libmaple/iwdg.h>

#define iwdg_init_ms(N)	iwdg_init(IWDG_PRE_256, ((N) / 5))

#define RESET_FOR_BOOTLOADER		(0x4501)


// test-tone delta(inc/dec) calculation
//
// 0 ~ 8s -> 0 ~ VARIOMETER_MAX_VELOCITY(10m/s)
// velocity update frequency -> 50Hz
//   8000 / (1000 / 50) -> update 400 times
//   10 / 400 -> 0.025

#define TT_HALF_PERIOD		(6000.0)	// 6s
#define TT_UPDATE_FREQ		(50.0)

#define TT_UPDATE_DELTA		(VARIOMETER_MAX_VELOCITY / (TT_HALF_PERIOD / (1000.0 / TT_UPDATE_FREQ)))

//
//
//

#define TONE_VELOCITY_DAMPING		(0.4)

//
//
//

enum _DeviceMode
{
	DEVICE_MODE_UNDEF =0,
	DEVICE_MODE_VARIO,			// (1)
	DEVICE_MODE_UMS,			// (2)
	DEVICE_MODE_CALIBRATION,	// (3)
	DEVICE_MODE_SHUTDOWN,		// (4)
};

enum _VarioMode
{
	VARIO_MODE_INIT = 0,		// (0)
	VARIO_MODE_LANDING,			// (1)
	VARIO_MODE_FLYING,			// (2)
//	VARIO_MODE_SHUTDOWN,		// (3)
};

enum _CalibrationMode
{
	CAL_MODE_INIT = 0,
	CAL_MODE_MEASURE_READY,
	CAL_MODE_MEASURE,
	CAL_MODE_CALIBATE_READY,
	CAL_MODE_CALIBATE,
	CAL_MODE_DONE,
	CAL_MODE_RESET,
};

//
//
//

void board_init();

void changeDeviceMode(int mode, bool first = false);

void setup_vario();
void loop_vario();

void setup_ums();
void loop_ums();

void setup_calibration();
void loop_calibration();

void setup_shutdown();
void loop_shutdown();

void processLowBattery();
void processShutdownInterrupt();
void processCommand();

void commandModeSwitch(Command * cmd, ResponseStack * res);
void commandSoundLevel(Command * cmd, ResponseStack * res);
void commandToneTest(Command * cmd, ResponseStack * res);
void commandSendsorDump(Command * cmd, ResponseStack * res);
void commandQueryProperty(Command * cmd, ResponseStack * res);
void commandUpdateProperty(Command * cmd, ResponseStack * res);
void commandDumpProperties(Command * cmd, ResponseStack * res);
void commandAccelerometerCalibration(Command * cmd, ResponseStack * res);

void commandQueryBluetooth(Command * cmd, ResponseStack * res);
void commandUpdateBluetooth(Command * cmd, ResponseStack * res);
void commandAdjustBaudRate(Command * cmd, ResponseStack * res);

void calibration_changeMode(uint8_t mode);
void calibration_readyMeasure(int beepType);
void calibration_startMeasure();
void calibration_doCalibate();

int pushProperties(int start);


//
//
//

uint8_t deviceMode = DEVICE_MODE_VARIO;

uint8_t	varioMode; 		// sub-mode of vario-mode
uint8_t	calibMode;		// sub-mode of calibration-mode
uint8_t calInteractive;	// flag for interactive calibration, 0 -> non-interactive(default), others -> interactive

uint32_t deviceTick;	// global tick-count
uint32_t modeTick;		// mode-specific tick-count

void (* loop_main)(void) = 0;


//
// tone-test
//

uint8_t	toneTestFlag = false;

float	toneTestVelocity;
float	toneTestDelta;

//
// dump properties
//

int		dumpProp = -1;


//
//
//

static Tone melodyVarioReady[] =
{
	{ 262, 1000 / 4 }, 
	{ 196, 1000 / 8 }, 
	{ 196, 1000 / 8 }, 
	{ 220, 1000 / 4 }, 
	{ 196, 1000 / 4 }, 
	{   0, 1000 / 4 }, 
	{ 247, 1000 / 4 }, 
	{ 262, 1000 / 4 },
	{   0, 1000 / 8 }, 
};
static Tone melodyTakeOff[] =
{
	#if 0
	{ 262, 1000 / 4 }, 
	{ 196, 1000 / 8 }, 
	{ 196, 1000 / 8 }, 
	{ 220, 1000 / 4 }, 
	{ 196, 1000 / 4 }, 
	{   0, 1000 / 4 }, 
	{ 247, 1000 / 4 }, 
	{ 262, 1000 / 4 },
	{   0, 1000 / 8 }, 
	#else
	{ 600, 1000 / 1 }, 
	{   0, 1000 / 4 }, 
	{ 400, 1000 / 4 }, 
	{   0, 1000 / 4 }, 
	{ 400, 1000 / 4 }, 
	{   0, 1000 / 4 }, 
	#endif
};

static Tone melodyLanding[] =
{
	#if 0
	{ 262, 1000 / 4 }, 
	{ 196, 1000 / 8 }, 
	{ 196, 1000 / 8 }, 
	{ 220, 1000 / 4 }, 
	{ 196, 1000 / 4 }, 
	{   0, 1000 / 4 }, 
	{ 247, 1000 / 4 }, 
	{ 262, 1000 / 4 },
	{   0, 1000 / 8 }, 
	#else
	{ 400, 1000 / 1 }, 
	{   0, 1000 / 4 }, 
	{ 400, 1000 / 1 }, 
	{   0, 1000 / 4 }, 
	#endif
};

//
// declare I2C instance
//
// I2C1 is used by IMU : I2CDevice is proxy interface of I2C1
// I2C2 is used by EEPROM
//

#if 0
SoftWire Wire1(PB6, PB7, SOFT_FAST);
SoftWire Wire2(PB10, PB11, SOFT_FAST);
#else
TwoWire Wire1(1, I2C_FAST_MODE);
TwoWire Wire2(2, I2C_FAST_MODE);
#endif

// initialize some static member of I2CDevice(I2C1)
//

// set wire reference member to I2C1
TwoWire & I2CDevice::Wire = Wire1;

// set unlock callback function
unlockCallback I2CDevice::cbUnlock = MS5611::unlockI2C;

// declare EEPROMDriver
EEPROMDriver eeprom(Wire2);
//
GlobalConfig Config(eeprom, EEPROM_ADDRESS);

//

#if VARIOMETER_CLASSS == CLASS_KALMANVARIO
KalmanVario vario;
#else
Variometer vario;
#endif // VARIOMETER_CLASSS == CLASS_KALMANVARIO


//
// declare Serial relative instance
//
// BT uses Serial1
// GPS uses Serial2

NmeaParserEx nmeaParser(SerialEx2);


//
//
//

VarioSentence varioNmea(VARIOMETER_DEFAULT_NMEA_SENTENCE);


//
//
//

SensorReporter sensorReporter;


//
// IGC Logger
//

IGCLogger logger;


//
// Digital & Analog Input/Output
//

// generic digital input
InputKey keyMode;
InputKey keyShutdown;
InputKey keyUSB;
#if HW_VERSION == HW_VERSION_V1_REV2
InputKey keyAccelInt;
InputKey keyMagDReady;
#endif // HW_VERSION == HW_VERSION_V1_REV2
// functional input
FunctionKey	keyFunc;
// analog input
BatteryVoltage batVolt;

// generic digital output
OutputKey keyPowerGPS;
OutputKey keyPowerBT;
OutputKey keyPowerDev;
#if HW_VERSION == HW_VERSION_V1_REV2
//OutputKey keyAccelFSync;
OutputKey keyPowerIMU;
OutputKey keyPowerSD;
#endif // HW_VERSION == HW_VERSION_V1_REV2
// functional output
LEDFlasher  ledFlasher;


//
//
//

ToneGenerator toneGen;
TonePlayer tonePlayer(toneGen);

VarioBeeper varioBeeper(tonePlayer);

//
float beepVelocity;


//
//
//

CommandStack cmdStack;

CommandParser cmdParser1(CMD_FROM_USB, Serial, cmdStack); // USB serial parser
CommandParser cmdParser2(CMD_FROM_BT, SerialBT, cmdStack); // BT serial parser
FuncKeyParser keyParser(keyFunc, cmdStack, tonePlayer);

ResponseStack resStackUSB;
ResponseStack resStackBT;
ResponseStack * resActive = NULL;

volatile int commandReceiveFlag = 0; // when any new command is occured, set this. 


//
//
//

BluetoothMan btMan(SerialBT, nmeaParser, varioNmea, sensorReporter, resStackBT);


//
//
//

AccelCalibrator accelCalibrator;



//
//
//

void board_init()
{
	// Initialize Serials
	Serial.begin();
	//while (! Serial);
	
	SerialBT.begin(BAUDRATE_BT); 	// Serial1(USART1) : for BT
	//while (! SerialBT);
	
	SerialEx2.begin(BAUDRATE_GPS);	// Serial2(USART2) : for GPS
	//while (! SerialEx2);

	// Initialize I2C
	Wire1.begin();
	Wire2.begin();
	
	//Wire1.setClock(400000);
	//Wire2.setClock(120000);
	
	// input pins
	//keyMode.begin(PIN_MODE_SELECT, ACTIVE_LOW); // not used
	keyShutdown.begin(PIN_SHDN_INT, ACTIVE_LOW);
	keyUSB.begin(PIN_USB_DETECT, ACTIVE_HIGH);
	#if HW_VERSION == HW_VERSION_V1_REV2
	keyAccelInt.begin(PIN_IMU_INTA, ACTIVE_HIGH);
	keyMagDReady.begin(PIN_IMU_DRDY, ACTIVE_LOW);
	#endif // HW_VERSION == HW_VERSION_V1_REV2
	// function-key
	keyFunc.begin(PIN_FUNC_INPUT, ACTIVE_HIGH);
	// adc input
	batVolt.begin(PIN_ADC_BATTERY);	
	
	// output pins
	#if HW_VERSION == HW_VERSION_V1
	keyPowerGPS.begin(PIN_GPS_EN, ACTIVE_LOW, OUTPUT_INACTIVE);
	keyPowerBT.begin(PIN_BT_EN, ACTIVE_LOW, OUTPUT_ACTIVE);
	//keyPowerDev.begin(PIN_KILL_PWR, ACTIVE_LOW, OUTPUT_ACTIVE);
	#elif HW_VERSION == HW_VERSION_V1_REV2
	keyPowerGPS.begin(PIN_GPS_EN, ACTIVE_HIGH, OUTPUT_INACTIVE);
	keyPowerBT.begin(PIN_BT_EN, ACTIVE_HIGH, OUTPUT_INACTIVE);
	//keyPowerDev.begin(PIN_KILL_PWR, ACTIVE_LOW, OUTPUT_ACTIVE);
	//keyAccelFSync.begin(PIN_IMU_FSYNC, ACTIVE_HIGH, OUTPUT_INACTIVE);
	keyPowerIMU.begin(PIN_IMU_EN, ACTIVE_HIGH, OUTPUT_INACTIVE);
	keyPowerSD.begin(PIN_SD_EN, ACTIVE_HIGH, OUTPUT_INACTIVE);
	#endif // HW_VERSION == HW_VERSION_V1_REV2
	// state beacon
	ledFlasher.begin(PIN_MCU_STATE, ACTIVE_LOW);
	ledFlasher.turnOn();
}

void board_reset()
{
	//
	tonePlayer.setTone(NOTE_C3, Config.volume.effect);
	delay(2000);
	
	// reset!!
	nvic_sys_reset();
	while(1);	
}

void board_reboot()
{
	#if 0
	// Enable clocks for the backup domain registers
	RCC_APB1PeriphClockCmd(RCC_APB1Periph_PWR | RCC_APB1Periph_BKP, ENABLE);
	// Disable backup register write protection
	PWR_BackupAccessCmd(ENABLE);
	// store value in DR10
	BKP_WriteBackupRegister(BKP_DR10, RESET_FOR_BOOTLOADER);
	// Re-enable backup register write protection
	PWR_BackupAccessCmd(DISABLE);
	#else
	bkp_init();
	//	rcc_clk_enable(RCC_PWR);
	//	rcc_clk_enable(RCC_BKP);
	bkp_enable_writes();
	bkp_write(10, RESET_FOR_BOOTLOADER);
	bkp_disable_writes();
	#endif
	
	// reset!!
	nvic_sys_reset();
	while(1);	
}

//
//
//

void changeDeviceMode(int mode, bool first)
{
	// post process
	if (! first)
	{
		switch (deviceMode)
		{
		case DEVICE_MODE_VARIO :
			// clean-up something
			vario.end();
			// close logger file if is logging
			logger.end(nmeaParser.getDateTime());
			// turn-off SD & wait a moment
			#if HW_VERSION == HW_VERSION_V1_REV2
			keyPowerSD.disable();
			delay(100);
			#endif // HW_VERSION == HW_VERSION_V1_REV2
			break;
		case DEVICE_MODE_CALIBRATION :
			// nop
			break;
		case DEVICE_MODE_UMS :
			// turn-off SD & wait a moment
			#if HW_VERSION == HW_VERSION_V1_REV2
			keyPowerSD.disable();
			delay(100);
			#endif // HW_VERSION == HW_VERSION_V1_REV2
			break;
		}
	}

	// start new mode
	switch ((deviceMode = mode))
	{
	case DEVICE_MODE_VARIO :
		setup_vario();
		loop_main = loop_vario;	
		break;
	case DEVICE_MODE_UMS :
		setup_ums();
		loop_main = loop_ums;
		break;
	case DEVICE_MODE_CALIBRATION :
		setup_calibration();
		loop_main = loop_calibration;
		break;
	case DEVICE_MODE_SHUTDOWN :
		setup_shutdown();
		loop_main = loop_shutdown;
		break;
	}
}


//
//
//

void setup()
{
	// init global variables
	// ...
	
	//
	board_init();
	
	// ToneGenerator uses PIN_PWM_H(PA8 : Timer1, Channel1)
	toneGen.begin(PIN_PWM_H);
	tonePlayer.setVolume(Config.volume.vario);	
	
	
	//
	Config.reset();
	Config.readAll();
	delay(100);
	Config.readAll();
	tonePlayer.setTone(0);
	
	//
	changeDeviceMode(DEVICE_MODE_VARIO, true);
	
	//
	//iwdg_init_ms(2 * 1000); // about 2.5s  : 40KHz /256 = 160Hz --> 2000 / 5 / 160 = 2.5
}


//
//
//

void loop()
{
	// main loop for each mode
	loop_main();

	// beep beep beep!
	tonePlayer.update();	
	// start voltage measurement periodically
	batVolt.update();
	// MCU State : LED Blinking
	ledFlasher.update();
	
	
	//
	// common functions
	//
	
	// process command from serial or key
	processCommand();
	
	// low battery!!
	processLowBattery();
	
	// check shutdown interrupts and prepare shutdown
	processShutdownInterrupt();	
	
	//
	if (dumpProp >= 0)
		dumpProp = pushProperties(dumpProp);	

	//
	while (resStackUSB.available())
		Serial.write(resStackUSB.read());	
	
	//
	//iwdg_feed();
}


//
//
//

void setup_vario()
{
	//
	varioMode = VARIO_MODE_INIT;
	
	tonePlayer.setTone(NOTE_G3, Config.volume.effect);	
	delay(500);
	tonePlayer.setTone(0);
	delay(200);
	tonePlayer.setTone(NOTE_G3, Config.volume.effect);
	delay(200);
	tonePlayer.setTone(0);
	delay(200);
	tonePlayer.setTone(NOTE_G3, Config.volume.effect);
	delay(200);
	tonePlayer.setTone(0);
	delay(1000);
	
	
	// turn-on All : IMU, SD, GPS, BT
	#if HW_VERSION == HW_VERSION_V1_REV2
	keyPowerIMU.enable();
	delay(200);
	#if ! KOBO_SUPPORT
	keyPowerSD.enable();
	delay(200);
	#endif
	#endif // HW_VERSION == HW_VERSION_V1_REV2
	//tonePlayer.setTone(NOTE_C4, Config.volume.effect);
	keyPowerGPS.enable();
	//delay(200);
	#if ! KOBO_SUPPORT
	//tonePlayer.setTone(NOTE_F4, Config.volume.effect);
	keyPowerBT.enable();
	//delay(200);
	#endif

	for (int i = 0; i < 10; i++)
	{
		ledFlasher.turnOff();
		delay(100);
		ledFlasher.turnOn();
		delay(100);
	}
	
	Wire.setClock(400000);
	for (int i = 0; i < 10; i++)
	{
		tonePlayer.setTone(NOTE_C4, Config.volume.effect);
		delay(200);
		tonePlayer.setTone(0);

		Wire.beginTransmission(0x77);
		byte error = Wire.endTransmission();
		
		if (error == 0)
			break;
		
		ledFlasher.turnOff();
		delay(1000);
		ledFlasher.turnOn();
	}

	tonePlayer.setTone(NOTE_C3, Config.volume.effect);
	delay(200);
	tonePlayer.setTone(0);
	
	//
	logger.init();

	//
	#if 0
	imu.init();
	
	for (int i = 0; i < 100; i++)
	{
		while (! imu.dataReady());
		imu.updateData();
	}
	
	// initialize kalman filtered vertical velocity calculator
	vertVel.init(imu.getAltitude(), 
				imu.getVelocity(),
				Config.kalman.sigmaP, // POSITION_MEASURE_STANDARD_DEVIATION,
				Config.kalman.igmaA, // ACCELERATION_MEASURE_STANDARD_DEVIATION,
				millis());		
	#endif
	
	#if VARIOMETER_CLASSS == CLASS_KALMANVARIO
	//vario.begin(KF_ZMEAS_VARIANCE, KF_ZACCEL_VARIANCE, KF_ACCELBIAS_VARIANCE);
	vario.begin(Config.kalman.var_zmeas, Config.kalman.var_zaccel, Config.kalman.var_accelbias);
	#else
	vario.begin(Config.kalman.sigmaP, Config.kalman.sigmaA);
	#endif // VARIOMETER_CLASSS == CLASS_KALMANVARIO


	// led flash as init-state
	ledFlasher.blink(BTYPE_LONG_ON_SHORT_OFF);

	// start vario-loop
	//tonePlayer.setMelody(&startTone[0], sizeof(startTone) / sizeof(startTone[0]), 1, PLAY_PREEMPTIVE, Config.volume.effect);
	tonePlayer.setBeep(NOTE_C4, 800, 500, 2, Config.volume.effect);
	
	//
	deviceTick = millis();
	beepVelocity = 0.0;
}

void loop_vario()
{
	//
	vario.update();
	
	if (vario.available())
	{
		//
		float velocity = vario.getVelocity();
		beepVelocity = beepVelocity + (velocity - beepVelocity) * Config.vario.dampingFactor; 	// beepVelocity * (1 - DAMPING_FACTOR) + velocity * DAMPING_FACTOR
		
		if (toneTestFlag)
		{
			//if (millis() - toneTestTick > TONE_TEST_DELAY)
			{
				toneTestVelocity = toneTestVelocity + toneTestDelta;
				
				if (toneTestVelocity < VARIOMETER_MIN_VELOCITY)
					toneTestDelta = TT_UPDATE_DELTA;
				if (toneTestVelocity > VARIOMETER_MAX_VELOCITY)
					toneTestDelta = -TT_UPDATE_DELTA;
				
				//toneTestTick = millis();
			}

			varioBeeper.setVelocity(toneTestVelocity);
		}
		else
		{
			if (! Config.volume.autoTurnOn || varioMode == VARIO_MODE_FLYING)
				varioBeeper.setVelocity(beepVelocity);
			//Serial.println(velocity);
		}

		//
		{
			#if ! KOBO_SUPPORT // Kobo never go to auto shutdown --> update device tick always
			if (beepVelocity < STABLE_SINKING_THRESHOLD || STABLE_CLIMBING_THRESHOLD < beepVelocity)
			#endif 
				deviceTick = millis(); // reset tick because it's not quiet.
			
			if (commandReceiveFlag)
			{
				deviceTick = millis(); // reset tick because it's not quiet.
				commandReceiveFlag = 0;
			}
			
			//if ((millis() - deviceTick) > AUTO_SHUTDOWN_THRESHOLD)
			if ((Config.threshold.auto_shutdown_vario) && ((millis() - deviceTick) > Config.threshold.auto_shutdown_vario))
			{
				Serial.println("Now process auto-shutdown!!");
				
				changeDeviceMode(DEVICE_MODE_SHUTDOWN);
				return;
			}
		}
		
		//
		sensorReporter.update(vario.getAccelData(), vario.getGyroData(), vario.getPressure(), vario.getTemperature());
		
		//
		float altitude = vario.getCalibratedAltitude(); // getCalibratedAltitude or getAltitude
		logger.update(altitude);
		//Serial.print(altitude); Serial.print(", "); Serial.println(vario.getAltitude2());
		
		// update vario sentence periodically
		if (varioNmea.checkInterval())
//			varioNmea.begin(altitude, vario.getVelocity(), vario.getTemperature(), batVolt.getVoltage());
			varioNmea.begin(altitude, vario.getVelocity(), vario.getTemperature(), vario.getPressure(), batVolt.getVoltage());
		
		//
		vario.flush();
	}	
	
	// read & prase gps sentence
	nmeaParser.update(/*vario.getCalibratedAltitude()*/);
	
	// send any prepared sentence to BT
	btMan.update();	

	// IGC sentence is available when it received a valid GGA. -> altitude is valid
	if (varioMode == VARIO_MODE_INIT  && nmeaParser.availableIGC())
	{
		// do position calibration
		//vertVel.calibratePosition(nmeaParser.getAltitude());
		vario.calibrateAltitude(nmeaParser.getAltitude());
		
		// now ready to fly~~~
		varioMode = VARIO_MODE_LANDING;

		//		
		ledFlasher.blink(BTYPE_LONG_ON_OFF);
		// play ready melody~~~
		tonePlayer.setMelody(&melodyVarioReady[0], sizeof(melodyVarioReady) / sizeof(melodyVarioReady[0]), 1, PLAY_PREEMPTIVE, Config.volume.effect);
	}
	else if (varioMode == VARIO_MODE_LANDING)
	{
		if (nmeaParser.getSpeed() > FLIGHT_START_MIN_SPEED && nmeaParser.getDateTime())
		{
			//
			varioMode = VARIO_MODE_FLYING;
			
			ledFlasher.blink(BTYPE_SHORT_ON_OFF);
			// play take-off melody
			tonePlayer.setMelody(&melodyTakeOff[0], sizeof(melodyTakeOff) / sizeof(melodyTakeOff[0]), 1, PLAY_PREEMPTIVE, Config.volume.effect);
			
			// start logging & change mode
			logger.begin(nmeaParser.getDateTime());
			
			// set mode-tick
			modeTick = millis();
		}
	}
	else if (varioMode == VARIO_MODE_FLYING)
	{
		if (nmeaParser.getSpeed() < FLIGHT_START_MIN_SPEED)
		{
			if ((millis() - modeTick) > FLIGHT_LANDING_THRESHOLD)
			{
				//
				varioMode = VARIO_MODE_LANDING;
				
				//
				ledFlasher.blink(BTYPE_LONG_ON_OFF);
				// play landing melody
				tonePlayer.setMelody(&melodyLanding[0], sizeof(melodyLanding) / sizeof(melodyLanding[0]), 1, PLAY_PREEMPTIVE, Config.volume.effect);
				
				// stop logging & change mode
				logger.end(nmeaParser.getDateTime());
			}
		}
		else
		{
			// reset modeTick
			modeTick = millis();
		}
	}
	
	// check logging state
	if (logger.isLogging())
	{
		// nmeaParser parses GPS sentence and converts it to IGC sentence
		
		//static unsigned long tick = millis();
		//static int index = 0;
		
		//if ((millis()-tick) > time_interval)
		{		
			while (nmeaParser.availableIGC())
				logger.write(nmeaParser.readIGC());
		}
	}
}


//
//
//


void setup_ums()
{
	// turn-off GPS & IMU
	keyPowerGPS.disable();
	#if HW_VERSION == HW_VERSION_V1_REV2
	keyPowerIMU.disable();
	#endif // HW_VERSION == HW_VERSION_V1_REV2
	// turn-on SD & BT
	#if HW_VERSION == HW_VERSION_V1_REV2
	keyPowerSD.enable();
	#endif // HW_VERSION == HW_VERSION_V1_REV2
	keyPowerBT.enable();
	delay(100);
	
	
	//
	Serial.end();
	
	//
	SdCard.begin(SDCARD_CS, SD_SCK_HZ(F_CPU/2)); // SPI_QUARTER_SPEED);
	
	uint32_t numberOfBlocks = SdCard.cardSize();
	//SerialDbg.print("Number of Blocks = "); SerialDbg.println(numberOfBlocks);
	
	if (numberOfBlocks)
	{
		usb_mal_init(numberOfBlocks);
		//SerialDbg.print("cardSize = "); SerialDbg.println(numberOfBlocks * 512);

		//
		//SerialDbg.println("USBMassStorage.begin");
		USBMassStorage.begin();	
		
		//
		ledFlasher.blink(BTYPE_BLINK_2_LONG_ON);
		//
		tonePlayer.setBeep(NOTE_G4, 500, 300, 2, Config.volume.effect);
		
		// set mode-tick
		modeTick = millis();
	}
	else
	{
		// synchronous beep!!
		tonePlayer.beep(NOTE_C3, 200, 3, Config.volume.effect);
		// return to vario mode
		changeDeviceMode(DEVICE_MODE_VARIO);
	}
}

void loop_ums()
{
	//
	USBMassStorage.loop();
	
	//
	ledFlasher.update();
	tonePlayer.update();
	
	// reset mode-tick when usb is plugged
	if (keyUSB.read() == INPUT_ACTIVE)
		modeTick = millis(); 

	// turn-off if it have been unplugged while a threshold
	//if ((millis() - modeTick) > AUTO_SHUTDOWN_THRESHOLD)
	if ((Config.threshold.auto_shutdown_ums) && ((millis() - modeTick) > Config.threshold.auto_shutdown_ums))
	{
		// synchronous beep!!
		tonePlayer.beep(NOTE_C4, 400, 2, Config.volume.effect);
		// shutdown now
		changeDeviceMode(DEVICE_MODE_SHUTDOWN);
	}
}

//
//
//

#define HIGH_BEEP_FREQ 			(1000)
#define LOW_BEEP_FREQ 			(100)
#define BASE_BEEP_DURATION 		(100)

#define BEEP_MEASURE_READY		(1)
#define BEEP_MEASURE_SUCCESS	(2)
#define BEEP_MEASURE_FAIL		(3)

#define MEASURE_READY_DELAY 	(3000)
#define CALIBRATE_READY_DELAY	(1000)
#define CALIBATE_RESET_DELAY	(2000)

void calibration_changeMode(uint8_t mode)
{
	// set mode & reset tick
	calibMode = mode;
	deviceTick = millis();
	
	if (calInteractive)
		resStackBT.push(CMD_ACCEL_CALIBRATION, RPARAM_CAL_MODE_CHANGED, mode);
}

void calibration_readyMeasure(int beepType)
{
	// ready measure
	Serial.println("ready measure....");
	
	//
	switch (beepType)
	{
	case BEEP_MEASURE_SUCCESS :
		// HIGH BEEP : BBBB_
		tonePlayer.setBeep(HIGH_BEEP_FREQ, BASE_BEEP_DURATION * 5, BASE_BEEP_DURATION, 1, KEY_VOLUME);
		break;
	case BEEP_MEASURE_FAIL :
		// LOW BEEP : bbbb_
		tonePlayer.setBeep(LOW_BEEP_FREQ, BASE_BEEP_DURATION * 5, BASE_BEEP_DURATION, 1, KEY_VOLUME);
		break;
	case BEEP_MEASURE_READY :
	default :
		// HIGH BEEP : B___B___
		tonePlayer.setBeep(HIGH_BEEP_FREQ, BASE_BEEP_DURATION * 4, BASE_BEEP_DURATION, 2, Config.volume.effect);
		break;
	}
	// 0___0___ ...
	ledFlasher.blink(BTYPE_SHORT_ON_LONG_OFF);

	// change mode
	calibration_changeMode(CAL_MODE_MEASURE_READY);
}

void calibration_startMeasure()
{
	// start measure
	Serial.println("start measure....");
	accelCalibrator.startMeasure();
	
	// HIGH BEEP : BBB___BBB___BBB___
	tonePlayer.setBeep(HIGH_BEEP_FREQ, BASE_BEEP_DURATION * 6, BASE_BEEP_DURATION * 3, 3, Config.volume.effect);
	// O_O_ ...
	ledFlasher.blink(BTYPE_SHORT_ON_OFF);

	// change mode
	calibration_changeMode(CAL_MODE_MEASURE);
}

void calibration_readyCalibrate()
{
	// HIGH BEEP : BBBB_
	tonePlayer.setBeep(HIGH_BEEP_FREQ, BASE_BEEP_DURATION * 5, BASE_BEEP_DURATION, 1, KEY_VOLUME);
	
	// change mode
	calibration_changeMode(CAL_MODE_CALIBATE_READY);
}
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

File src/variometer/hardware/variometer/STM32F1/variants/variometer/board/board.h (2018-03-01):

/******************************************************************************
 * The MIT License
 *
 * Copyright (c) 2011 LeafLabs, LLC.
 *
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
 * THE SOFTWARE IS PROVIDED "AS IS", WITHOUT WARRANTY OF ANY KIND,
 * EXPRESS OR IMPLIED, INCLUDING BUT NOT LIMITED TO THE WARRANTIES OF
 * MERCHANTABILITY, FITNESS FOR A PARTICULAR PURPOSE AND
 * NONINFRINGEMENT. IN NO EVENT SHALL THE AUTHORS OR COPYRIGHT HOLDERS
 * BE LIABLE FOR ANY CLAIM, DAMAGES OR OTHER LIABILITY, WHETHER IN AN
 * ACTION OF CONTRACT, TORT OR OTHERWISE, ARISING FROM, OUT OF OR IN
 * CONNECTION WITH THE SOFTWARE OR THE USE OR OTHER DEALINGS IN THE
 * SOFTWARE.
 *****************************************************************************/

/**
 * @file   wirish/boards/maple_mini/include/board/board.h
 * @author Marti Bolivar <mbolivar@leaflabs.com>
 * @brief  Maple Mini board header.
 *
 * See wirish/boards/maple/include/board/board.h for more information
 * on these definitions.
 */

#ifndef _BOARD_STM32_VARIOMETER_H_
#define _BOARD_STM32_VARIOMETER_H_

#define CYCLES_PER_MICROSECOND	(F_CPU / 1000000U)
#define SYSTICK_RELOAD_VAL     (F_CPU/1000) - 1 /* takes a cycle to reload */

#define BOARD_NR_USARTS           3
#define BOARD_USART1_TX_PIN       26
#define BOARD_USART1_RX_PIN       25
#define BOARD_USART2_TX_PIN       9
#define BOARD_USART2_RX_PIN       8
#define BOARD_USART3_TX_PIN       1
#define BOARD_USART3_RX_PIN       0

#define BOARD_NR_SPI              2
#define BOARD_SPI1_NSS_PIN        7
#define BOARD_SPI1_MOSI_PIN       4
#define BOARD_SPI1_MISO_PIN       5
#define BOARD_SPI1_SCK_PIN        6
#define BOARD_SPI2_NSS_PIN        31
#define BOARD_SPI2_MOSI_PIN       28
#define BOARD_SPI2_MISO_PIN       29
#define BOARD_SPI2_SCK_PIN        30

#define BOARD_NR_GPIO_PINS        34
#define BOARD_NR_PWM_PINS         12
#define BOARD_NR_ADC_PINS          9
#define BOARD_NR_USED_PINS         4

#define BOARD_JTMS_SWDIO_PIN      22
#define BOARD_JTCK_SWCLK_PIN      21
#define BOARD_JTDI_PIN            20
#define BOARD_JTDO_PIN            19
#define BOARD_NJTRST_PIN          18

#define BOARD_USB_DISC_DEV        GPIOB
#define BOARD_USB_DISC_BIT        9

#define LED_BUILTIN PB1

enum {
    PB11, PB10, PB2, PB0, PA7, PA6, PA5, PA4, PA3, PA2, PA1, PA0, PC15, PC14,
    PC13, PB7, PB6, PB5, PB4, PB3, PA15, PA14, PA13, PA12, PA11, PA10, PA9,
    PA8, PB15, PB14, PB13, PB12, PB8, PB1
};

#endif // _BOARD_STM32_VARIOMETER_H_

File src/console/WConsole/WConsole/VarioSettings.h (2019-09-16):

// VarioSettings.h
//

#ifndef __VARIOSETTINGS_H__
#define __VARIOSETTINGS_H__


/////////////////////////////////////////////////////////////////////////////
//

// command code
#define CMD_STATUS				'ST'
#define CMD_RESET				'RS'
#define CMD_SHUTDOWN			'SD'
#define CMD_FIRMWARE_VERSION	'FV'
#define CMD_MODE_SWITCH			'MS'
#define CMD_SOUND_LEVEL			'SL'
#define CMD_TONE_TEST			'TT'
#define CMD_DUMP_SENSOR			'DS'
#define CMD_DUMP_PROPERTY		'DP'
#define CMD_DUMP_CONFIG			'DC'
#define CMD_BLOCK_GPS_NMEA		'BG'
#define CMD_BLOCK_VARIO_NMEA	'BV'
#define CMD_FACTORY_RESET		'FR'
#define CMD_RESTORE_PARAM		'RP'
#define CMD_SAVE_PARAM			'SP'
#define CMD_QUERY_PARAM			'QP'
#define CMD_UPDATE_PARAM		'UP'
#define CMD_ACCEL_CALIBRATION	'AC'
#define CMD_RUN_BOOTLOADER		'RB'
#define CMD_BLUETOOTH_QUERY		'BQ'
#define CMD_BLUETOOTH_UPDATE	'BU'
#define CMD_ADJUST_BT_BAUDRATE	'BB'

// response code <-- replaced by command code
/*
#define RCODE_RESULT			'RS'
#define RCODE_OK				'OK'
#define RCODE_FAIL				'FA'
#define RCODE_ERROR				'ER'
#define RCODE_NOT_READY			'NR'
#define RCODE_UNAVAILABLE		'UA'
#define RCODE_DUMP_PARAM		'DP'
#define RCODE_QUERY_PARAM		'QP'
#define RCODE_UPDATE_PARAM		'UP'
*/

// PARAM : use in range 0x0000 ~ 0xFFFF, 0xFFFFFFFF(-1) means unused param
//     -> result of command processing              : 0x0000 ~ 0x0100
//     -> accelerometer calibration result/status   : 0x1000 ~ 0x1FFF
//     -> mode switch return                        : 0x2000 ~ 0x2FFF
//     -> id of property                            : 0x9000 ~ 0xFFFF

#define RPARAM_SUCCESS				(0)
#define RPARAM_OK					(0)

#define RPARAM_FAIL					(1)
#define RPARAM_INVALID_COMMAND		(2)
#define RPARAM_INVALID_PROPERTY		(3)
#define RPARAM_NOT_READY			(4)
#define RPARAM_UNAVAILABLE			(5)
#define RPARAM_NOT_ALLOWED			(6)
#define RPARAM_INVALID_PARAMETER	(7)
#define RPARAM_INVALID_DATA			(8)

#define RPARAM_CAL_START			(0x1000)
#define RPARAM_CAL_MODE_CHANGED		(0x1001)	// INIT->READY->MEASURE->CALIBATE->DONE or STOP
#define RPARAM_CAL_MEASURED_RESULT	(0x1003)	// validation, orient, accel standard deviation
#define RPARAM_CAL_DONE				(0x1002)	// calibration accel x/y/z
#define RPARAM_CAL_ACCELEROMETER 	(0x1004)	// calibrated accel x/y/z

#define RPARAM_SW_BASE				(0x2000)
#define RPARAM_SW_VARIO				(0x2001)
#define RPARAM_SW_UMS				(0x2002)
#define RPARAM_SW_CALIBRATION		(0x2003)

#define RPARAM_BT_BAUDRATE			(0x3001)
#define RPARAM_BT_NAME				(0x3002)
#define RPARAM_BT_KEY				(0x3003)



// mode switch
#define PARAM_MS_QUERY			(0)	// response with current mode
#define PARAM_MS_VARIO			(1)
#define PARAM_MS_UMS			(2)
#define PARAM_MS_CALIBRATION	(3)

// device status
/*
#define PARAM_DS_ALL			(0)
#define PARAM_DS_IMU			(1)
#define PARAM_DS_SDCARD			(2)
#define PARAM_DS_GPS			(3)
#define PARAM_DS_VOLTAGE		(4)
*/

// sensor dump
#define PARAM_DU_NONE			(0)
#define PARAM_DU_ACCELEROMETER	(1<<0)
#define PARAM_DU_GYROSCOPE		(1<<1)
#define PARAM_DU_PRESSURE		(1<<2)
#define PARAM_DU_TEMPERATURE	(1<<3)
#define PARAM_DU_ALL			(0x0F)

// nmea sentence
/*
#define PARAM_NM_UNBLOCK		(0)
#define PARAM_NM_BLOCK			(1)
*/

//  tone test
#define PARAM_TT_STOP			(0)
#define PARAM_TT_START			(1)

// sound level
#define PARAM_SL_ALL			(0)
#define PARAM_SL_VARIO			(1)
#define PARAM_SL_EFFECT			(2)

#define PARAM_SL_MUTE			(0x1000)
#define PARAM_SL_MEDIUM			(0x1001)
#define PARAM_SL_LOUD			(0x1002)


// device reset
#define PARAM_RS_NOW			(0)
#define PARAM_RS_AFTER_SAVE		(1)

// accelerometer calibration
#define PARAM_AC_MEASURE		(1)
#define PARAM_AC_CALIBRATE		(2)
#define PARAM_AC_STOP			(3)
#define PARAM_AC_QUERY_STATUS	(4)
#define PARAM_AC_RESET			(5)

// bluetooth
#define PARAM_BT_BAUDRATE		(1)
#define PARAM_BT_NAME			(2)
#define PARAM_BT_KEY			(3)


#define MAX_PROFILE_SIZE		(16)
#define MAX_STRING_SIZE			(16)
#define TONE_TABLE_COUNT		(12)


enum GliderType
{
	GTYPE_UNKNOWNM,
	GTYPE_PARAGLIDER,
	GTYPE_HG_FLEX,
	GTYPE_HG_RIGID,
	GTYPE_SAILPLANE,
	GTYPE_PPG_FOOT,
	GTYPE_PPG_WHEEL
};

enum VarioSentence
{
	VSENTENCE_LK8,
	VSENTENCE_LXNAV,
};

enum PARAM_VarType
{
	PARAM_INT8_T,
	PARAM_INT16_T,
	PARAM_INT32_T,
	PARAM_UINT8_T,
	PARAM_UINT16_T,
	PARAM_UINT32_T,
	PARAM_FLOAT,
	PARAM_STRING
};
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

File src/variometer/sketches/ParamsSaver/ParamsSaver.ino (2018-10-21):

// ParamsSaver.ino
//

#include <DefaultSettings.h>
#include <GlobalConfig.h>
#include <EEPROMDriver.h>
#include <Digit.h>

#define STRSTACK_START		16*1024		// half-memory reserved for string stacks
#define STRSTACK_SIZE		16 * 4		// each string max size -> it can save up to 256 string 

const char * pilot = "AKKDONG";
const char * manufacture = "Niviuk";
const char * model = "IcePeak 6";

const char * strings[] = // max string size limits to 16 * 4
{
	"blah blah",
	"woopa doopa",
};

TwoWire wire(2, I2C_FAST_MODE);
EEPROMDriver eeprom(wire);
GlobalConfig Config(eeprom, EEPROM_ADDRESS);

void printDigit(double value, int width)
{
	Digit digit;
	
	digit.begin(value, 2);
	int size = digit.size();
	for (int i = 0; i < width - size; i++)
		Serial.print(" ");
	while (digit.available())
		Serial.write(digit.get());
}

void printDigit(long value, int width)
{
	Digit digit;
	
	digit.begin(value);
	int size = digit.size();
	for (int i = 0; i < width - size; i++)
		Serial.print(" ");
	while (digit.available())
		Serial.write(digit.get());
}

void printParams()
{
	//
	// GliderInfo
	Serial.println("Glider Info"); 
	Serial.print("   "); 
	switch(Config.glider.type)
	{
	case GTYPE_PARAGLIDER	:
		Serial.println("Paraglider");
		break;
	case GTYPE_HG_FLEX		:
		Serial.println("Hanglider Flex");
		break;
	case GTYPE_HG_RIGID		:	
		Serial.println("Hanglider Rigid");
		break;
	case GTYPE_SAILPLANE	:
		Serial.println("Sailplane");
		break;
	case GTYPE_PPG_FOOT		:
		Serial.println("Powered Paraglider Foot");
		break;
	case GTYPE_PPG_WHEEL	:
		Serial.println("Powered Paraglider Wheel");
		break;
	case GTYPE_UNKNOWNM		:
	default :
		Serial.println("Unset");
		break;
	}
	Serial.print("   "); 
	Serial.print(Config.glider.manufacture);
	Serial.print(" "); 
	Serial.println(Config.glider.model);
	Serial.println("");
	
	// Logger
	Serial.println("IGC-Logger"); 
	Serial.print("  "); Serial.println(Config.logger.enable ? "Enable" : "Disable");
	Serial.print("  takeoff speed : "); Serial.println(Config.logger.takeoff_speed);
	Serial.print("  landing timeout : "); Serial.println(Config.logger.landing_timeout);
	Serial.print("  logging interval : "); Serial.println(Config.logger.logging_interval);
	Serial.print("  pilot : "); Serial.println(Config.logger.pilot);
	Serial.print("  timezone : GMT"); Serial.print(Config.logger.timezone > 0 ? "+" : ""); Serial.println((int)Config.logger.timezone);
	Serial.println("");
	
	// Vario Settings
	Serial.println("Vario Settings");
	Serial.print("  sink threshold : "); Serial.println(Config.vario.sinkThreshold);
	Serial.print("  climb threshold : "); Serial.println(Config.vario.climbThreshold);
	Serial.print("  sensitivity : "); Serial.println(Config.vario.sensitivity);
	Serial.print("  sentence : "); Serial.println(Config.vario.sentence == VARIOMETER_LK8_SENTENCE ? "LK8" : "LxNav");
	Serial.print("  baroOnly: "); Serial.println(Config.vario.baroOnly ? "Yes" : "No");
	Serial.print("  damping Factor: "); Serial.println(Config.vario.dampingFactor);
	Serial.println("");
	
	// Tone Table
	Serial.println("Tone Tables:");
	Serial.println("  vel, freq, period, duty");
	for (int i = 0; i < TONE_TABLE_COUNT; i++)
	{
		Serial.print("  "); 
		Serial.print(Config.toneTable[i].velocity);
		Serial.print(", ");
		Serial.print(Config.toneTable[i].freq);
		Serial.print(", ");
		Serial.print(Config.toneTable[i].period);
		Serial.print(", ");
		Serial.print(Config.toneTable[i].duty);
		Serial.println("");	
	}
	Serial.println("");
	
	// Volume Settings
	Serial.println("Volume Settings");
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

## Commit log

2017-10-13 reference documents & schematics
2017-10-13 pin assign
    [STM32F103xx-LQFP48 pin-out.xlsx]
2017-10-14 draft schamatic & some documents
    [MAX1676-Low Battery Detection Register Calculator.xlsx, STM32F103xx-LQFP48 pin-out.xlsx, Variometer-STM32.sch]
2017-10-15 support auto power off
    [STM32F103xx-LQFP48 pin-out.xlsx, Variometer-STM32.sch]
2017-10-15 update piezo driver circuit
    [Variometer-STM32.sch]
2017-10-15 add bootloader
    [BOM.xlsx, flash.cfg, stm32.cfg]
2017-10-16 add pizeo circuits
2017-10-17 invensense dmp & i2c wrapper
2017-10-17 sensor processing
2017-10-18 calculate vertical velocity suppport ms5611 on stm32 some reference circuit & datasheet change pin map : eeprom -> i2c2, spi2 -> spi1, ...
    [STM32F103xx-LQFP48 pin-out.xlsx]
2017-10-18 update schematic -> use LTC2950 : Push Button On/Off Controller -> re-assign pin -> change EEPROM from SPI to I2C interface -> SD-Card move from SPI2 to SPI1
    [MAX1676-Low Battery Detection Register Calculator.xlsx, STM32F103xx-LQFP48 pin-out.xlsx, Variometer-STM32.sch]
2017-10-20 add NmeaParser rename InertialMeasurementUnit to IMUModule
2017-10-20 fix schematic : change xxx_en ping, etc ...
    [Variometer-STM32.sch]
2017-10-21 begin layout
    [Variometer-STM32.sch]
2017-10-22 update BOM fix some Layout
    [BOM.xlsx, Variometer-STM32.sch]
2017-10-22 add gerber
    [drl001.drl]
2017-10-22 update pinmap document
    [STM32F103xx-LQFP48 pin-out.xlsx]
2017-10-23 fix some PCB DECAL modify schematic
    [BOM.xlsx, STM32F103xx-LQFP48 pin-out.xlsx, Variometer-STM32.sch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]
2017-10-24 parts re-numbering change part type
    [BOM.xlsx, Variometer-STM32.sch]
2017-10-25 add mode selection(DBG or UMS)
    [BOM.xlsx, STM32F103xx-LQFP48 pin-out.xlsx, Variometer-STM32.sch]
2017-10-26 fix NmeaParser : re-define parsing state add VarioSentence stubs & Digit
    [Variometer.ino]
2017-10-26 update FixedLenDigit add BatteryVoltage
    [Variometer.ino]
2017-10-26 test battery voltage, igc logging fix BatteryVoltage, IGCLogger, NmeaParserEx
    [Variometer.ino]
2017-10-27 fix IGCLogger - create proper named file update Readme.MD
    [Variometer.ino]
2017-10-27 final PCB artwork
    [STM32F103xx-LQFP48 pin-out.xlsx, Variometer-STM32.sch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]
2017-10-29 mode definition take-off, landing
2017-10-29 last schematic
2017-10-30 fix bootloader config.h -> change usb_en pin
    [Variometer.ino, config.h]
2017-10-31 add LEDFlasher
2017-11-01 add Function key parser, Sensor data reporter
2017-11-07 fix bugs NmeaParser, FunctionKey, FuncKeyParser, BluetoothMan implementation CommandStack add TonePlayer::setMemodyEx
    [Variometer.ino]
2017-11-07 implment no-interactive accelerometer calibration. TBD
2017-11-07 fix LEDFlasher
2017-11-08 NmeaParserEx bug fix : infinite loop re-arrange power-off by low-battery by power-key device mode change position(altitude) calibration
    [Variometer.ino]
2017-11-10 interactive calibration
2017-11-26 modify voltage divider : 270K -> 560K
2017-11-27 + UMS auto-shutdown + reset command
    [Variometer.ino]
2017-12-06 new regulator
2017-12-06 rev1 pin-map
    [STM32F103xx-LQFP48 pin-out.xlsx]
2017-12-07 rev.1 schematic
    [Variometer-STM32-Rev1.sch]
2017-12-12 add STM32Sleep library
2017-12-12 stm32 low-power mode
2017-12-13 mod beep table
    [Variometer-STM32-Rev1.sch]
2017-12-30 REV2 GERBER
    [Variometer-STM32-Rev2.sch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]
2018-01-09 windows console app
    [Variometer-STM32-Rev2.sch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]
2018-01-11 support rev2
    [STM32F103xx-LQFP48 pin-out.xlsx]
2018-02-02 change response format : %command,param,data,... change HardWare to TwoWire : update Arduino-STM32
2018-02-12 update response parameter success -> 0 fail -> others
    fix reload error
    MainActivity reloaded when close it.
    -> clear bluetooth connection listener on onDestroy
    [Variometer.ino]
2018-02-18 bias battery voltage
2018-02-18 fix calibration
2018-02-19 AN2557-STM32F10x IAP using the USART(StdPeriphDriver)
2018-03-01 stm32 vario board
2018-03-01 core of stm32 vario board is STM32F103CB
2018-03-01 bootloader-serial baudrate: 56700 -> 115200 remove x64 HD -> MD vario reboot command 'RB'
    [DownloaderDlg.cpp, serial.c]
2018-03-01 change bt uart baudrate: 38400 -> 57600
2018-03-02 vs file filters
2018-03-02 support to version of board
2018-03-03 flash erase/write bug fix
    [serial.c]
2018-03-03 volume setting bug fix
    [Variometer.ino]
2018-03-04 - BTConfig bug fix - add key-function : goto bootloader
    [BTConfig.ino, Variometer.ino]
2018-03-05 - increase serial buffer - add go bootloader key-function - fix BTConfig - firmware version command(test)
    [BTConfig.ino, Variometer.ino]
2018-03-07 VarioProg: implement device response
2018-03-13 igc bug fix -> sometimes longitude is saved as incorrect value: but i don't know why ^^;;;;; -> cut-off value(last digit of DDDMM.mmmm) causes the coordinates to shake
2018-03-29 vario-sentence uses raw pressure
2018-10-15 change lk8 pressure, vario, altitude precision change & fix AConsole pressure unit
2018-10-16 fix: LK8 pressure -> hPa * 100
    [Variometer.ino]
2018-10-21 case-design : FreeCAD
    [Button.FCStd, Case-Bottom.FCStd, Case-Top.FCStd]
2018-10-22 new case
    [Variometer-Case.FCStd]
2018-10-23 case working cont...
    [Button.FCStd, Case-Bottom-2.FCStd, Case-Top-2.FCStd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]
2018-10-24 case update
    [Case-Body.stl, Case-Button.stl, Case-Cover.stl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]
2018-10-25 update case
    [Case-Body.stl, Case-Button.stl, Variometer-Case.FCStd]
2018-10-31 mod case
    [Case-Body-wt-Hole.stl, Variometer-Case.FCStd]
2018-10-31 mod: case
    [Case-Body-wt-Hole.stl, Variometer-Case.FCStd]
2018-11-01 update case rev2
    [Case-Body-Rev2.stl, Case-Cover-Rev2.stl, Variometer-Case-Rev2.FCStd]
2018-11-05 fix: write data to bluetooth device when it is connected!
    [Variometer.ino]
2018-11-06 update case fix: send data only bluetooth is connected
    [Variometer-Case-Rev2.FCStd]
2018-11-06 case rev3
    [Case-Body-3.stl, Case-Cover-3.stl]
2018-11-08 new function: adjust bluetooth baudrate
    [Case-ButtonSlim.stl, Case-ButtonSpacer.stl, Variometer-Case-Rev2.FCStd]
2019-09-02 Kobo case (working)
    [Kobo.FCStd]
2019-09-02 Kobo case(working)
    [Kobo-Working.FCStd]
2019-09-03 update kobo case(working)
    [Kobo.FCStd]
2019-09-04 update Kobo case
    [Kobo-Bottom.stl, Kobo-Cover.stl, Kobo.FCStd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]
2019-09-30 support NMEA format command : some bugs are fixed change takeoff/landing melody
    [Variometer.ino]
2019-10-01 attach antenna to case
    [Kobo-Antenna.stl, Kobo.FCStd]
2019-10-04 update antenna (gps holder)
    [Kobo.FCStd]
2019-10-10 update 3d model
    [Kobo-Bottom.stl, Kobo.FCStd]
2019-10-11 update 3d model (tbd)
    [Kobo.FCStd]
2019-10-13 update 3d model (fin)
    [Kobo.FCStd]
2019-10-15 add revision 3
    [Variometer-STM32-Rev3.sch]
2019-10-16 revision 3 (tbd)
    [STM32F103xx-LQFP48 pin-out.xlsx]
2019-11-04 rev3 update
    [STM32F103xx-LQFP48 pin-out.xlsx, Variometer-STM32-Rev3.sch]
